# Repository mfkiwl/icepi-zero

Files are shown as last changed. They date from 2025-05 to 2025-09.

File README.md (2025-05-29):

# Icepi Zero - The portable FPGA development board. 



## What is the Icepi Zero?

Icepi Zero is an economical FPGA development board with a Raspberry Pi Zero form factor. It carries a Lattice ECP5 25F, enabling powerful designs while keeping a small portable size. It also has a HDMI port allowing easy digital video output.

[View PCB online](https://kicanvas.org/?github=https%3A%2F%2Fgithub.com%2Fcheyao%2Ficepi-zero%2Ftree%2Fmain%2Fhardware%2Fv1.1)



## Why Icepi Zero?

Currently most powerful FPGA boards on the market are expensive and bulky.

I've always wanted a low-cost portable FPGA with video output to make my own CPU, but there isn't any on the market.

The Icepi Zero aims to fix this. Carrying a powerful ECP5 FPGA on a small Raspberry Pi Zero form factor, it is the ultimate portable solution for FPGA development. Additionally packing a HDMI mini port and 3 USB-C ports, it allows interfacing with multiple external I/O devices.

Icepi Zero is for everyone: Students can use it to learn about the internals of modern processors. Gamers can use it to emulate old hardware. Programmers can use it to test their code on multiple architecturs.

Icepi Zero also has an on-board USB to JTAG converter, so no external programmers are needed. Moreover Icepi Zero is fully open-source, no strings attached. Fabricate your own boards if you want one!



## Features

- Raspberry Pi Zero form factor
- Lattice ECP5U FPGA:
    - 24k LUT
    - 112 KiB of RAM
- One MiniGPDI connector (it's HDM- but I don't have the money to buy a license...)
- Three USB-C Ports
- 256MiB 166MHz SDRAM
- MicroSD card slot
- On-board USB to JTAG and UART converter
- 40MHz external oscillator
- 128 Mbit of flash
- 4 user LEDs
- 1 user button

This powerful configuration allows the PCB to be used in numerous ways, including real time video processing, hardware AI acceleration and prototyping of ASICs.



## Usage

Check out the `firmware` folder for example code and compilation instructions!

## Contact

If there is any questions DM `@Cyao` on Hackclub Slack or `cyao.` on Discord. Mail is also accepted at `cyao _at_ duck.com`.

Thanks Hackclub for sponsering this! Check out [highway & undercity, a hackathon at Github HQ](https://highway.hackclub.com/?ref=recg6V5Pj0JbZghRM)

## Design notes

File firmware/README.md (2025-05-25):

# Icedev Zero Firmware

Welcome to the firmware folder! You can find numerous examples here:

- `blinky`: Classic LED counter!
- `counter`: Counter using the button as input :D
- `uart`: Uart transmission example

## Toolchain setup

Download the latest build of the [oss cad suit](https://github.com/YosysHQ/oss-cad-suite-build/releases/).

Unzip it anywhere and set shell command search path:
```
Linux              : export PATH=[path-to-bin]:$PATH
MacOS              : export PATH=[path-to-bin]:$PATH
Windows Powershell : $ENV:PATH = "[path-to-bin];" + $ENV:PATH
Windows cmd.exe    : PATH=[path-to-bin];%PATH%
```

## How to build

Just `cd` into the directories, and type `make`!

- `make install` installs the program to flash
- `make debug` installs the program to chip (bitstream lost on power loss)
- `make build` builds the bitstream
- `make clean` deletes all the temporary files
- `make` runs `make debug`

## Make your own!

Just copy the `icepi-zero.lpf` and `Makefile` to the root of your directory, call your main module `top`, and you are good to go!

## Pinout

To come soon

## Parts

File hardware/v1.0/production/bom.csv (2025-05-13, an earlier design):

Designator | Footprint | Quantity | Value | LCSC Part #
C1, C19, C23, C26, C42, C45, C47, C49, C7, C8, C9 | 0603 | 11 | 10uF | C19702
C10, C11, C12, C13, C14, C15, C18, C2, C20, C21, C24, C25, C27, C28, C38, C39, C40, C41, C43, C44, C46, C48, C50, C51, C52, C6 | 0402 | 26 | 100nF | C307331
C16, C17, C22, C3, C4, C5 | 0603 | 6 | 22uF | C59461
C29, C30, C31, C32, C33, C34, C35, C36 | 0402 | 8 | 22nF | C1532
C37 | 0402 | 1 | 100pF | C1546
D1, D2, D3, D4, D5 | 0603 | 5 | WHITE | C2290
D6 | 0603 | 1 | RED | C2286
FB1 | 0805 | 1 | 100R@100MHz | C1015
J2 | XKB Connection A71-05H4-111N1 | 1 | HDMI_C_1.3 | C2682170
J3, J4, J5 | USB_C_Receptacle_GCT_USB4105-xx-A_16P_TopMnt_Horizontal | 3 | USB_C_Receptacle_USB2.0_14P | C2765186
J6 | microSD_HC_SOFNG_TF-008 | 1 | Micro_SD_Card_Det2 | C428465
L1, L2, L3 | 0805 | 3 | 2.2uH | C1043
R1, R12, R14, R2, R3, R4, R5 | 0402 | 7 | 470 | C25117
R10, R36, R37, R38, R8 | 0402 | 5 | 15k | C25756
R11, R18, R19 | 0402 | 3 | 3.3k | C25890
R13, R32, R33, R34, R35, R6 | 0402 | 6 | 10k | C25744
R15 | 0402 | 1 | 100k | C25741
R16, R17, R22, R23, R24, R25, R31, R9 | 0402 | 8 | 4.7k | C25900
R20, R21, R26, R27, R29, R30 | 0402 | 6 | 5.1k | C25905
R28 | 0402 | 1 | 100 | C25076
R7 | 0402 | 1 | 12k | C25752
SW1 | SW_SPST_TL3342 | 1 | SW_Push | C318884
U1 | BGA-256_14.0x14.0mm_Layout16x16_P0.8mm_Ball0.45mm_Pad0.32mm_NSMD | 1 | ECP5U_12_CABGA256 | C1521614
U10 | TSOP-II-54_22.2x10.16mm_P0.8mm | 1 | W9825G6KH | C62246
U11 | SOIC-8_5.3x5.3mm_P1.27mm | 1 | W25Q128JVS | C97521
U2, U3, U4 | SOT-23-5 | 3 | TLV62569DBV | C141836
U5 | VSSOP-8_2.3x2mm_P0.5mm | 1 | PCA9306DC1 | C129510
U6 | QFN-20-1EP_4x4mm_P0.5mm_EP2.5x2.5mm | 1 | FT231XQ | C132159
U7, U8, U9 | Texas_DRT-3 | 3 | TPD2EUSB30A | C3011197
Y1 | Oscillator_SMD_SiT_PQFN-4Pin_2.5x2.0mm | 1 | SITxxxxxx-1x-33E-50.000000 | C1182928

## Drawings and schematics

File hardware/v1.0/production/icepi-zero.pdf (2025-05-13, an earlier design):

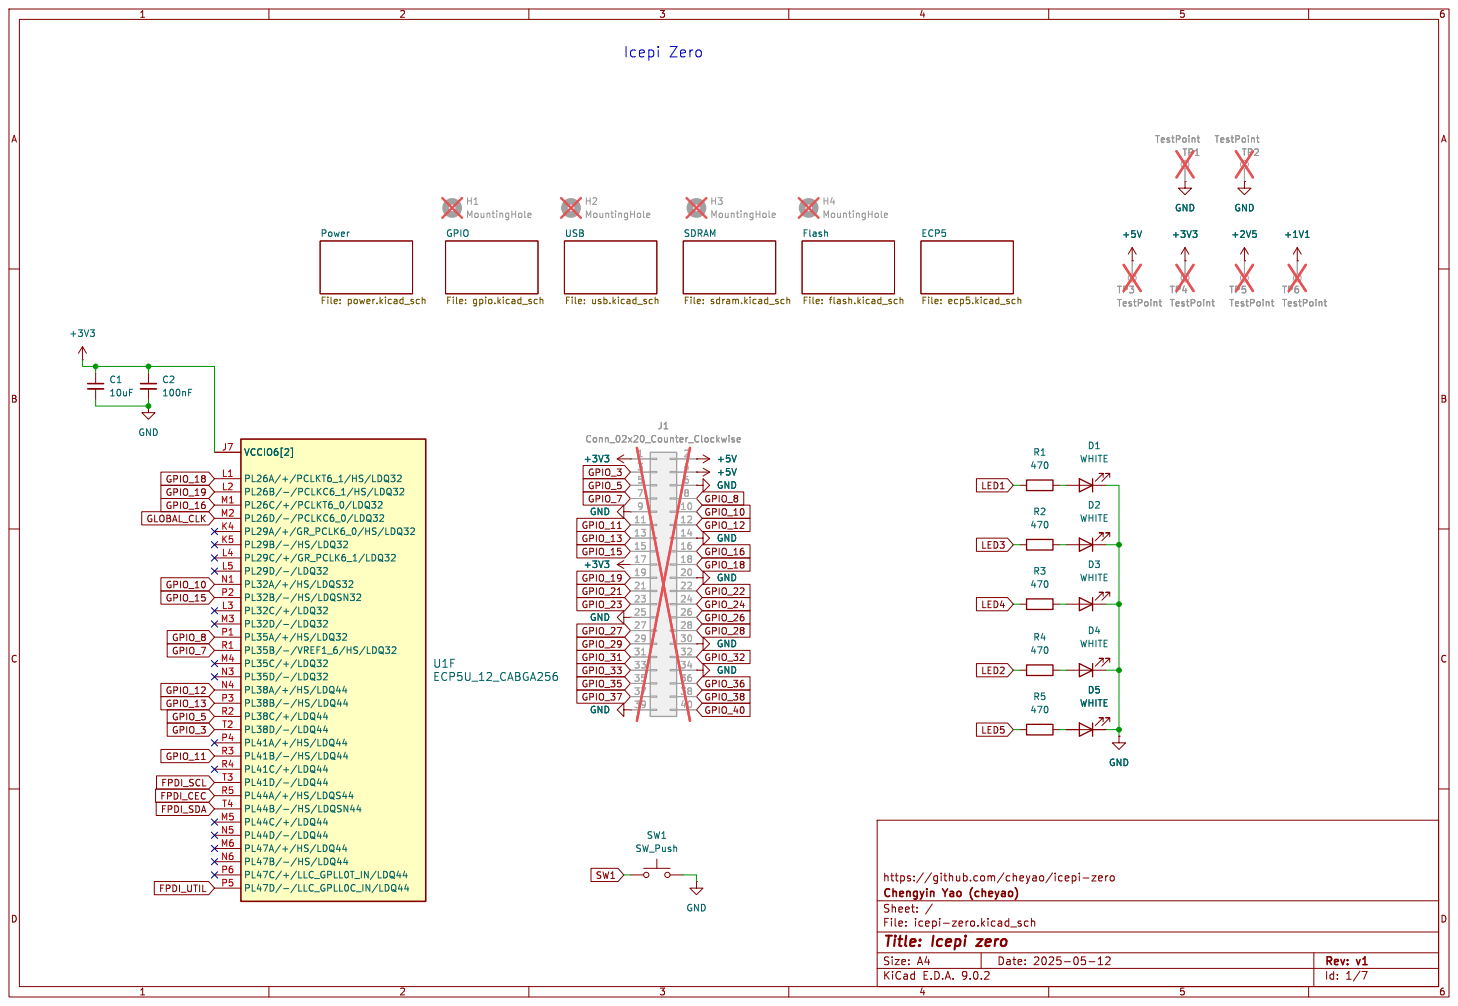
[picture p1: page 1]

TP1 TestPoint GND GND GND

https://github.com/cheyao/icepi-zero
File: icepi-zero.kicad_sch Sheet: / Chengyin Yao (cheyao)

Id: 1/7 Title: Icepi zero

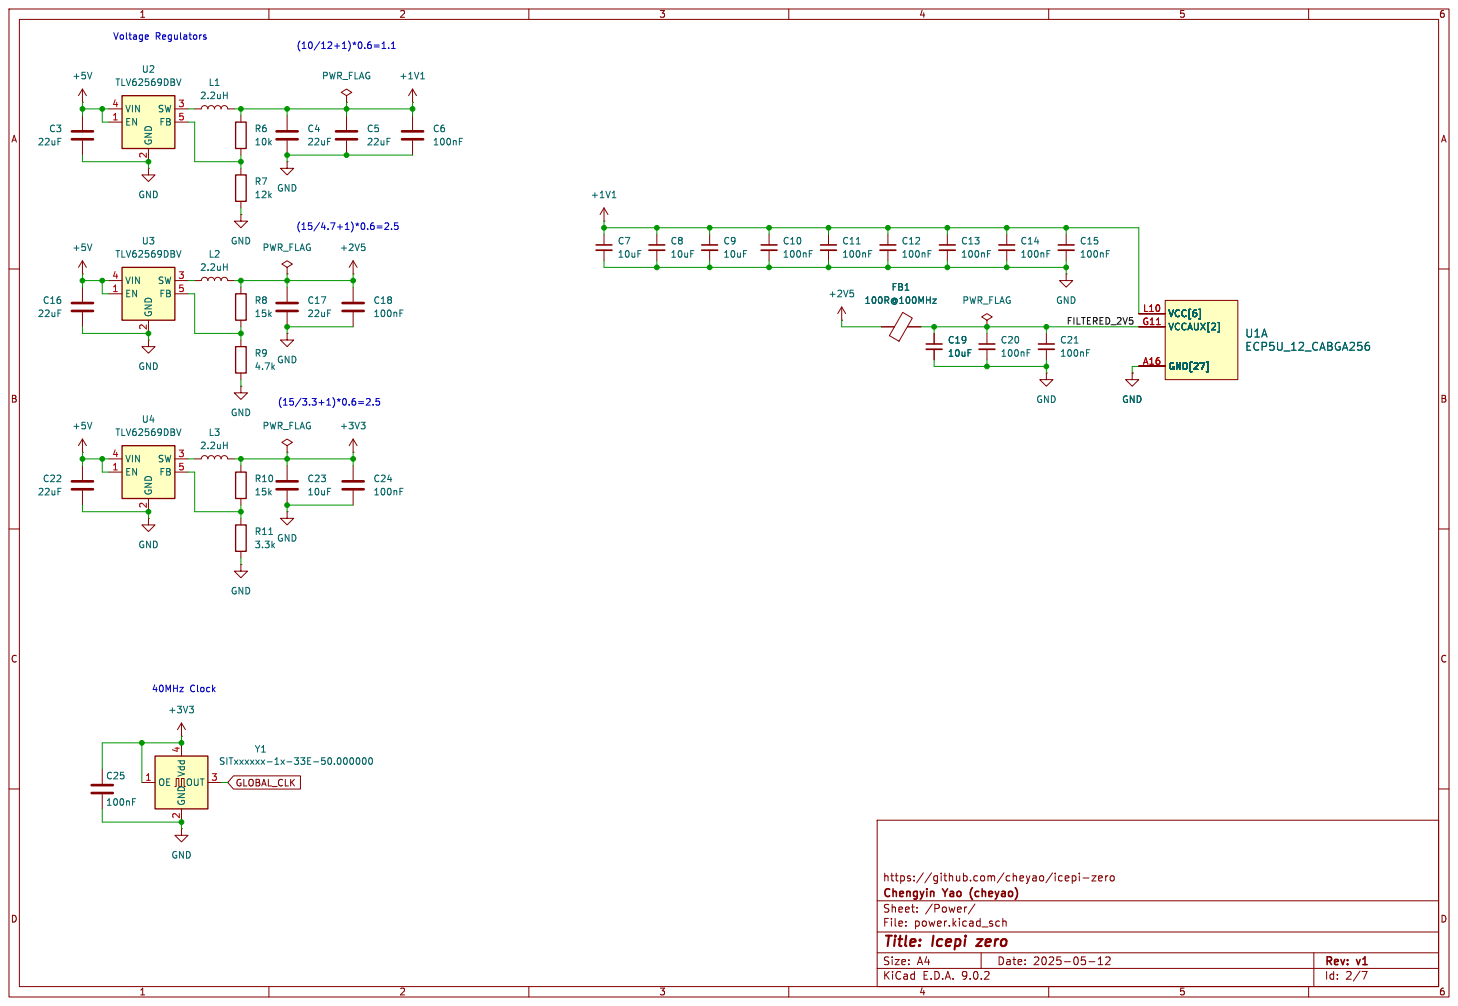
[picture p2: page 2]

https://github.com/cheyao/icepi-zero
File: power.kicad_sch Sheet: /Power/ Chengyin Yao (cheyao)

Id: 2/7 Title: Icepi zero

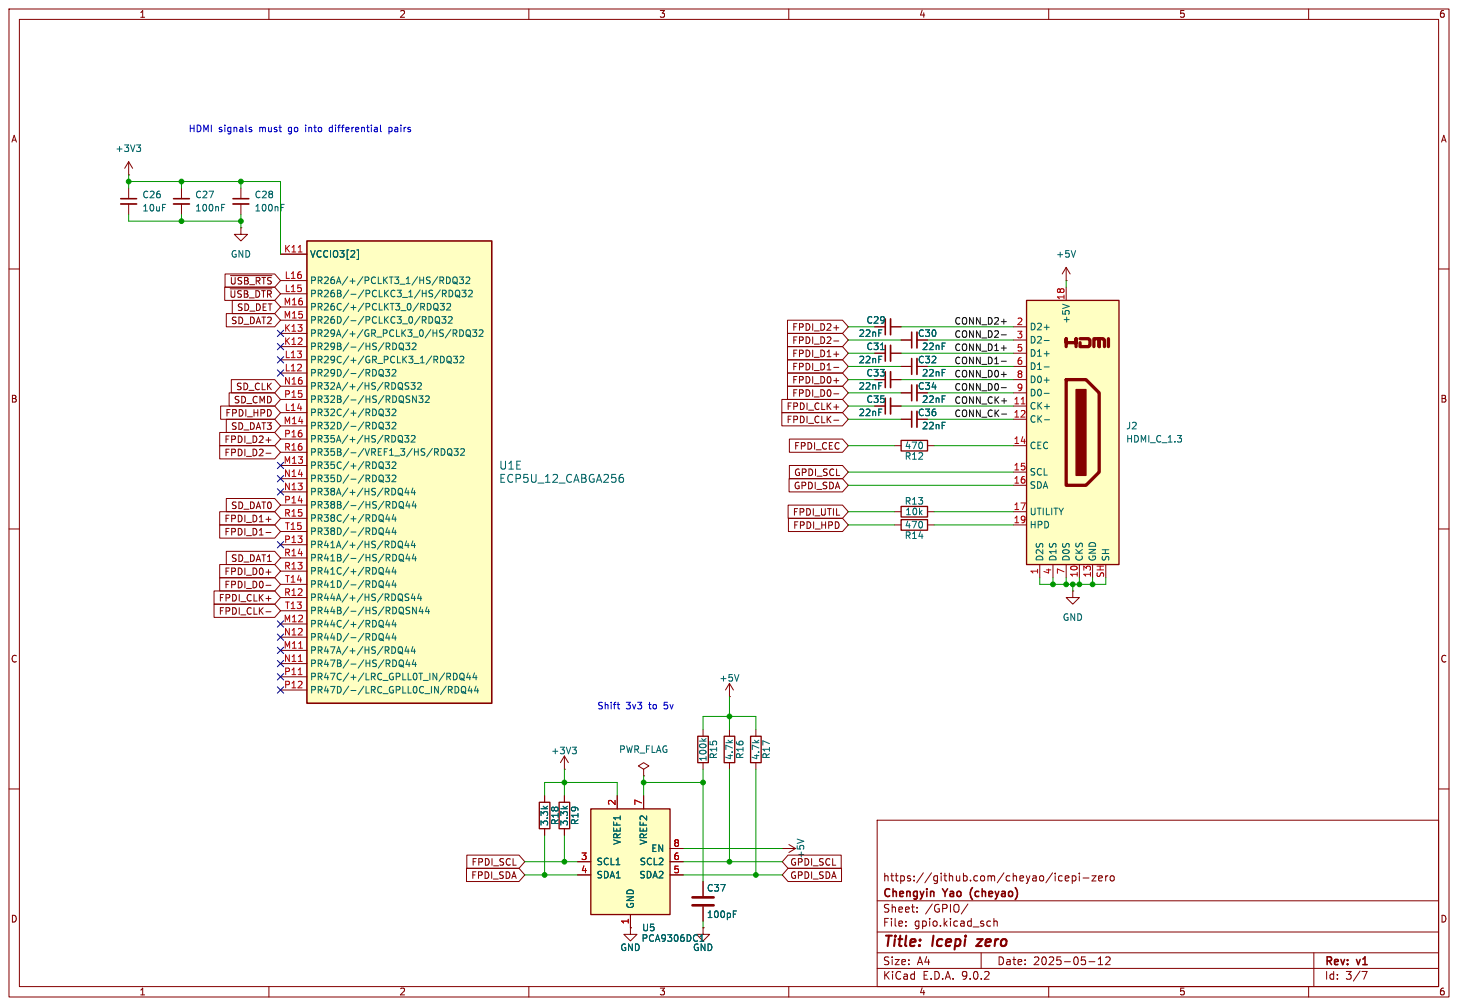
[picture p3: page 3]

7 CKS 10 GND 13 SH SH

https://github.com/cheyao/icepi-zero PWR_FLAG

File: gpio.kicad_sch Sheet: /GPIO/ Chengyin Yao (cheyao)

Id: 3/7 Title: Icepi zero

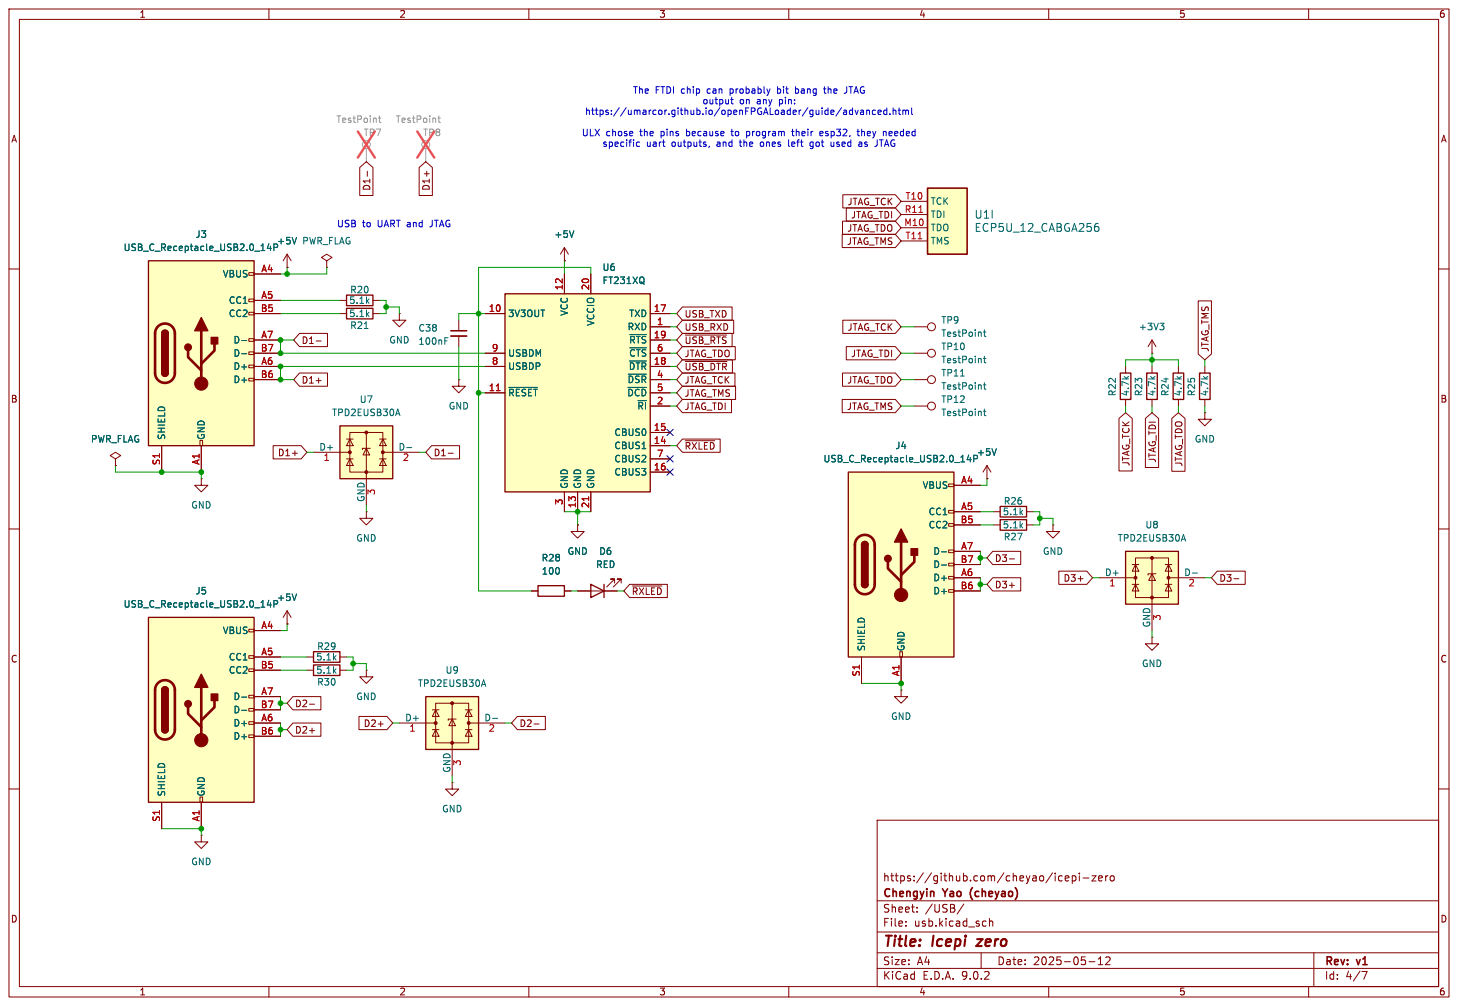
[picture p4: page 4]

https://umarcor.github.io/openFPGALoader/guide/advanced.html ULX chose the pins because to program their esp32, they needed
~{RXLED} JTAG_TCK

output on any pin:

USB to UART and JTAG

3 GND 13 VCCIO 20 GND 21 TXD 17 RXD 1 ~{RTS}19 ~{CTS}6 ~{DTR}18 ~{DSR}4 ~{DCD}5 ~{RI}2 CBUS0 15 CBUS1 14 CBUS2 7 CBUS3 16 U6 FT231XQ

3 GND 13 VCCIO 20 GND 21 TXD 17 RXD 1 ~{RTS}19 ~{CTS}6 ~{DTR}18 ~{DSR}4 ~{DCD}5 ~{RI}2 CBUS0 15 CBUS1 14 CBUS2 7 CBUS3 16 D6 RED

https://github.com/cheyao/icepi-zero
File: usb.kicad_sch Sheet: /USB/ Chengyin Yao (cheyao)

Id: 4/7 Title: Icepi zero

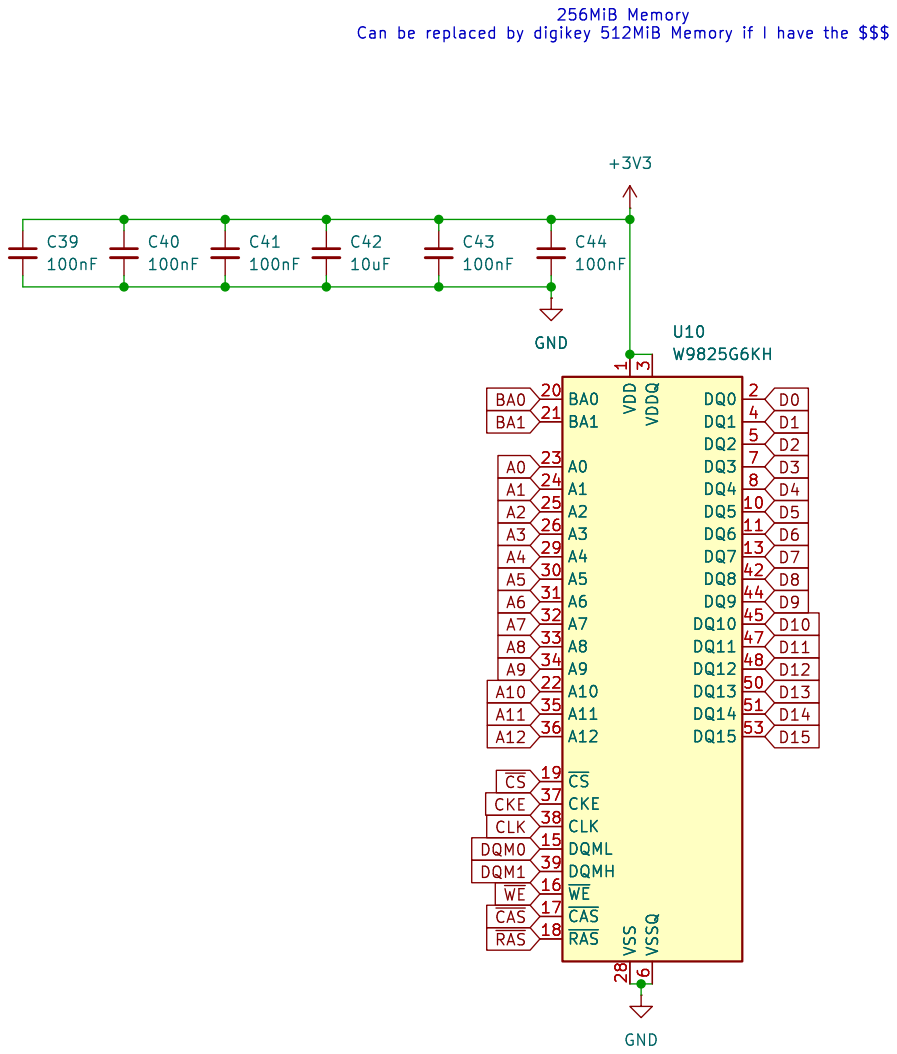
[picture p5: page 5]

https://github.com/cheyao/icepi-zero GND

File: sdram.kicad_sch Sheet: /SDRAM/ Chengyin Yao (cheyao)

Id: 5/7 Title: Icepi zero

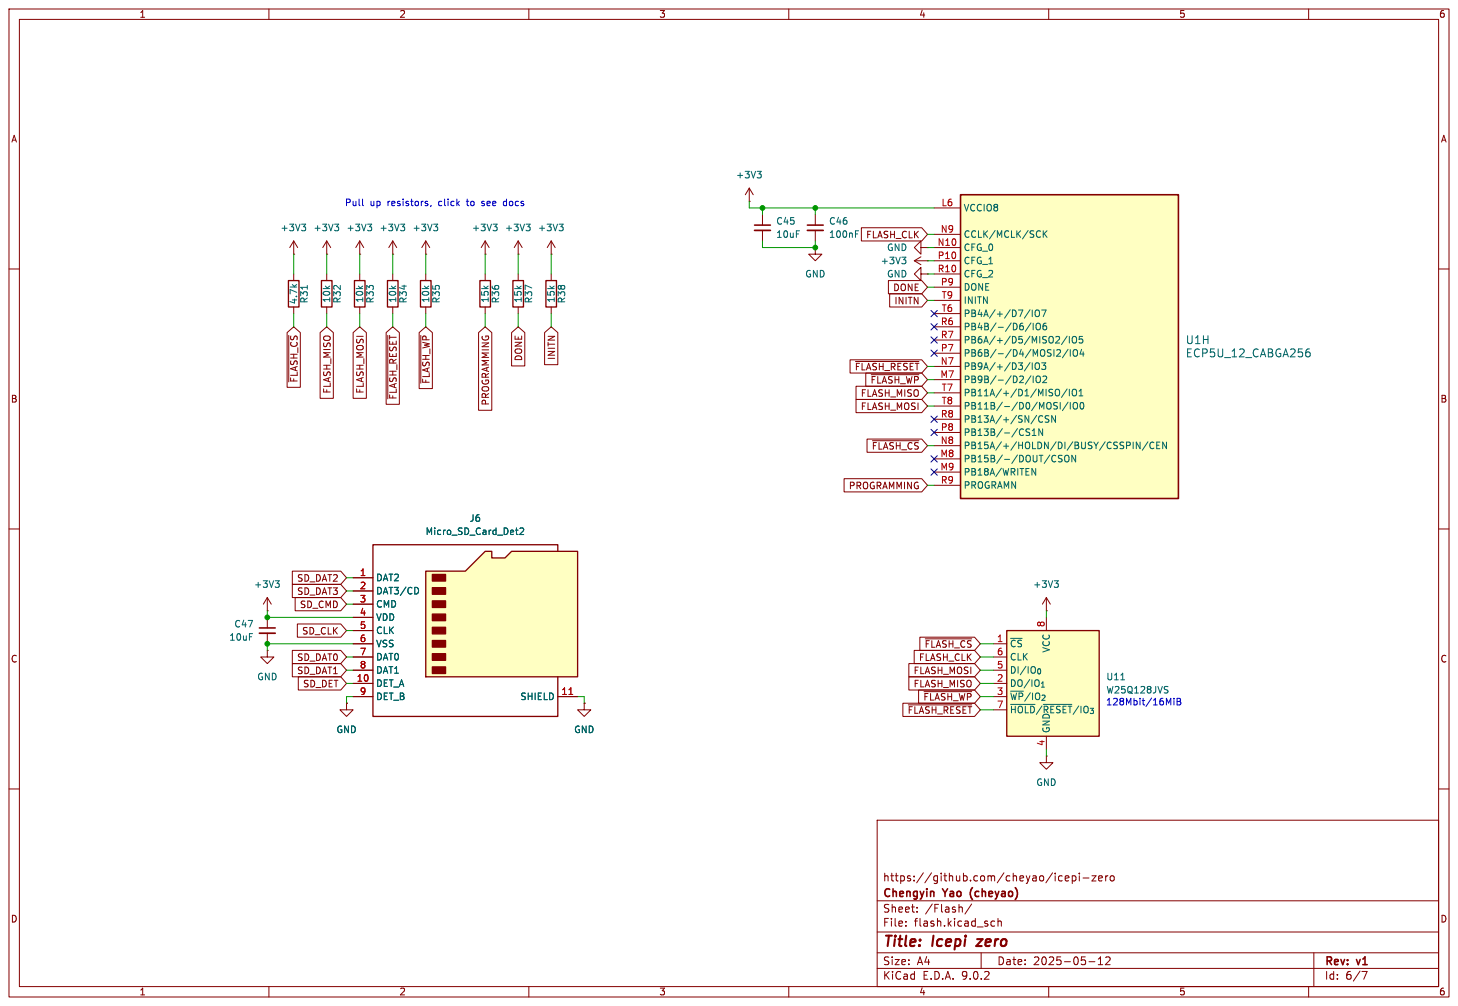
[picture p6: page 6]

File: flash.kicad_sch Sheet: /Flash/ Chengyin Yao (cheyao)

Id: 6/7 Title: Icepi zero

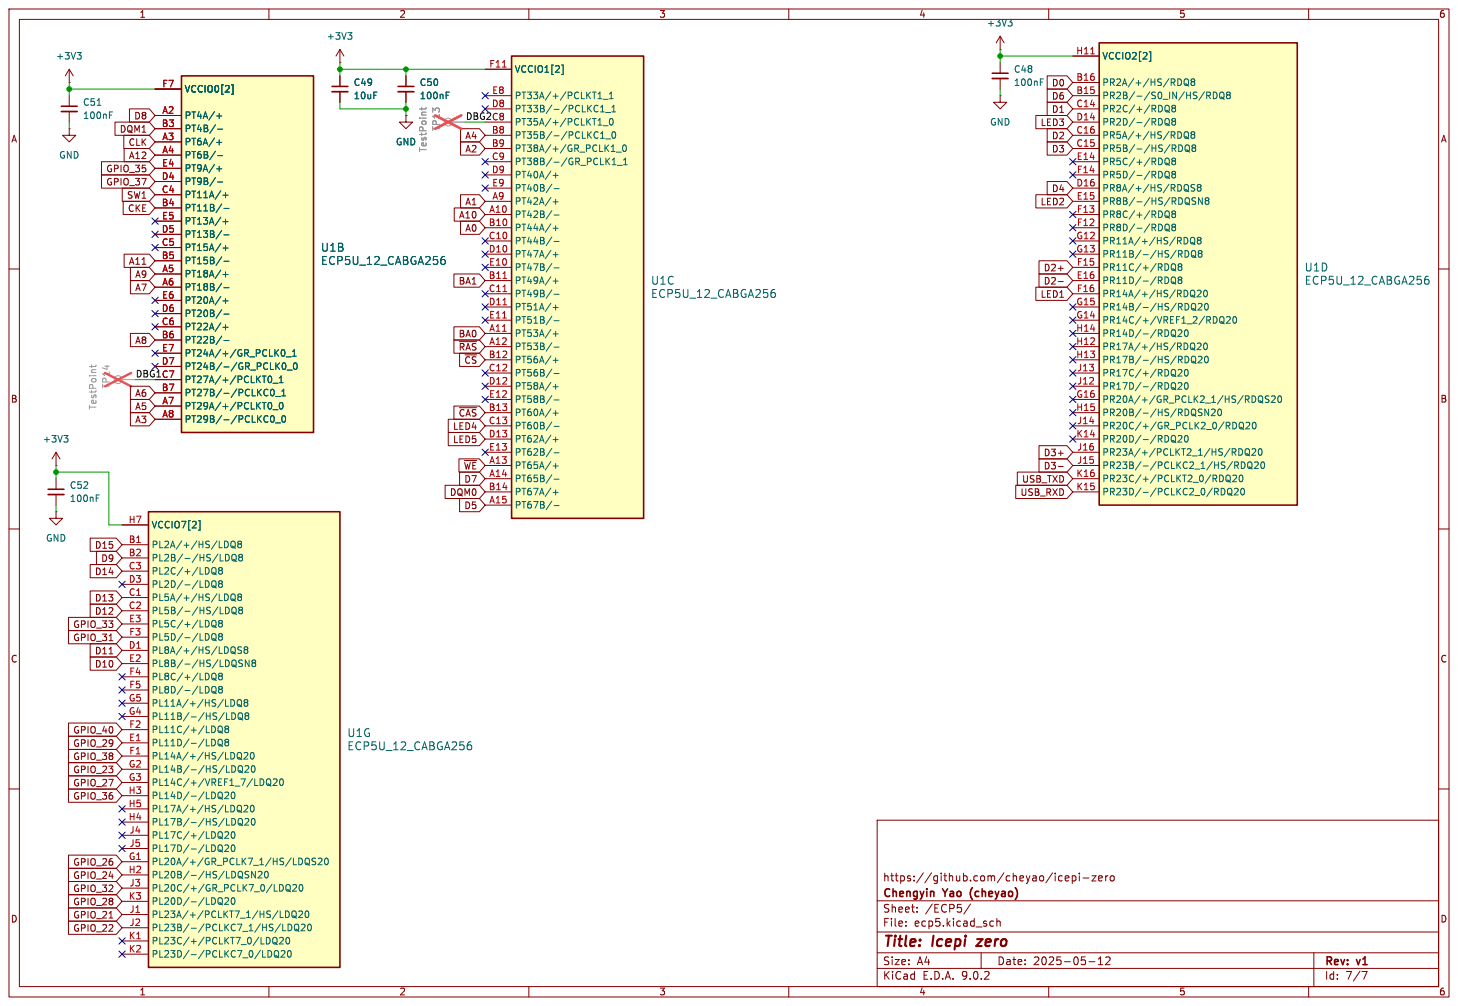
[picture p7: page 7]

https://github.com/cheyao/icepi-zero
File: ecp5.kicad_sch Sheet: /ECP5/ Chengyin Yao (cheyao)

Id: 7/7 Title: Icepi zero

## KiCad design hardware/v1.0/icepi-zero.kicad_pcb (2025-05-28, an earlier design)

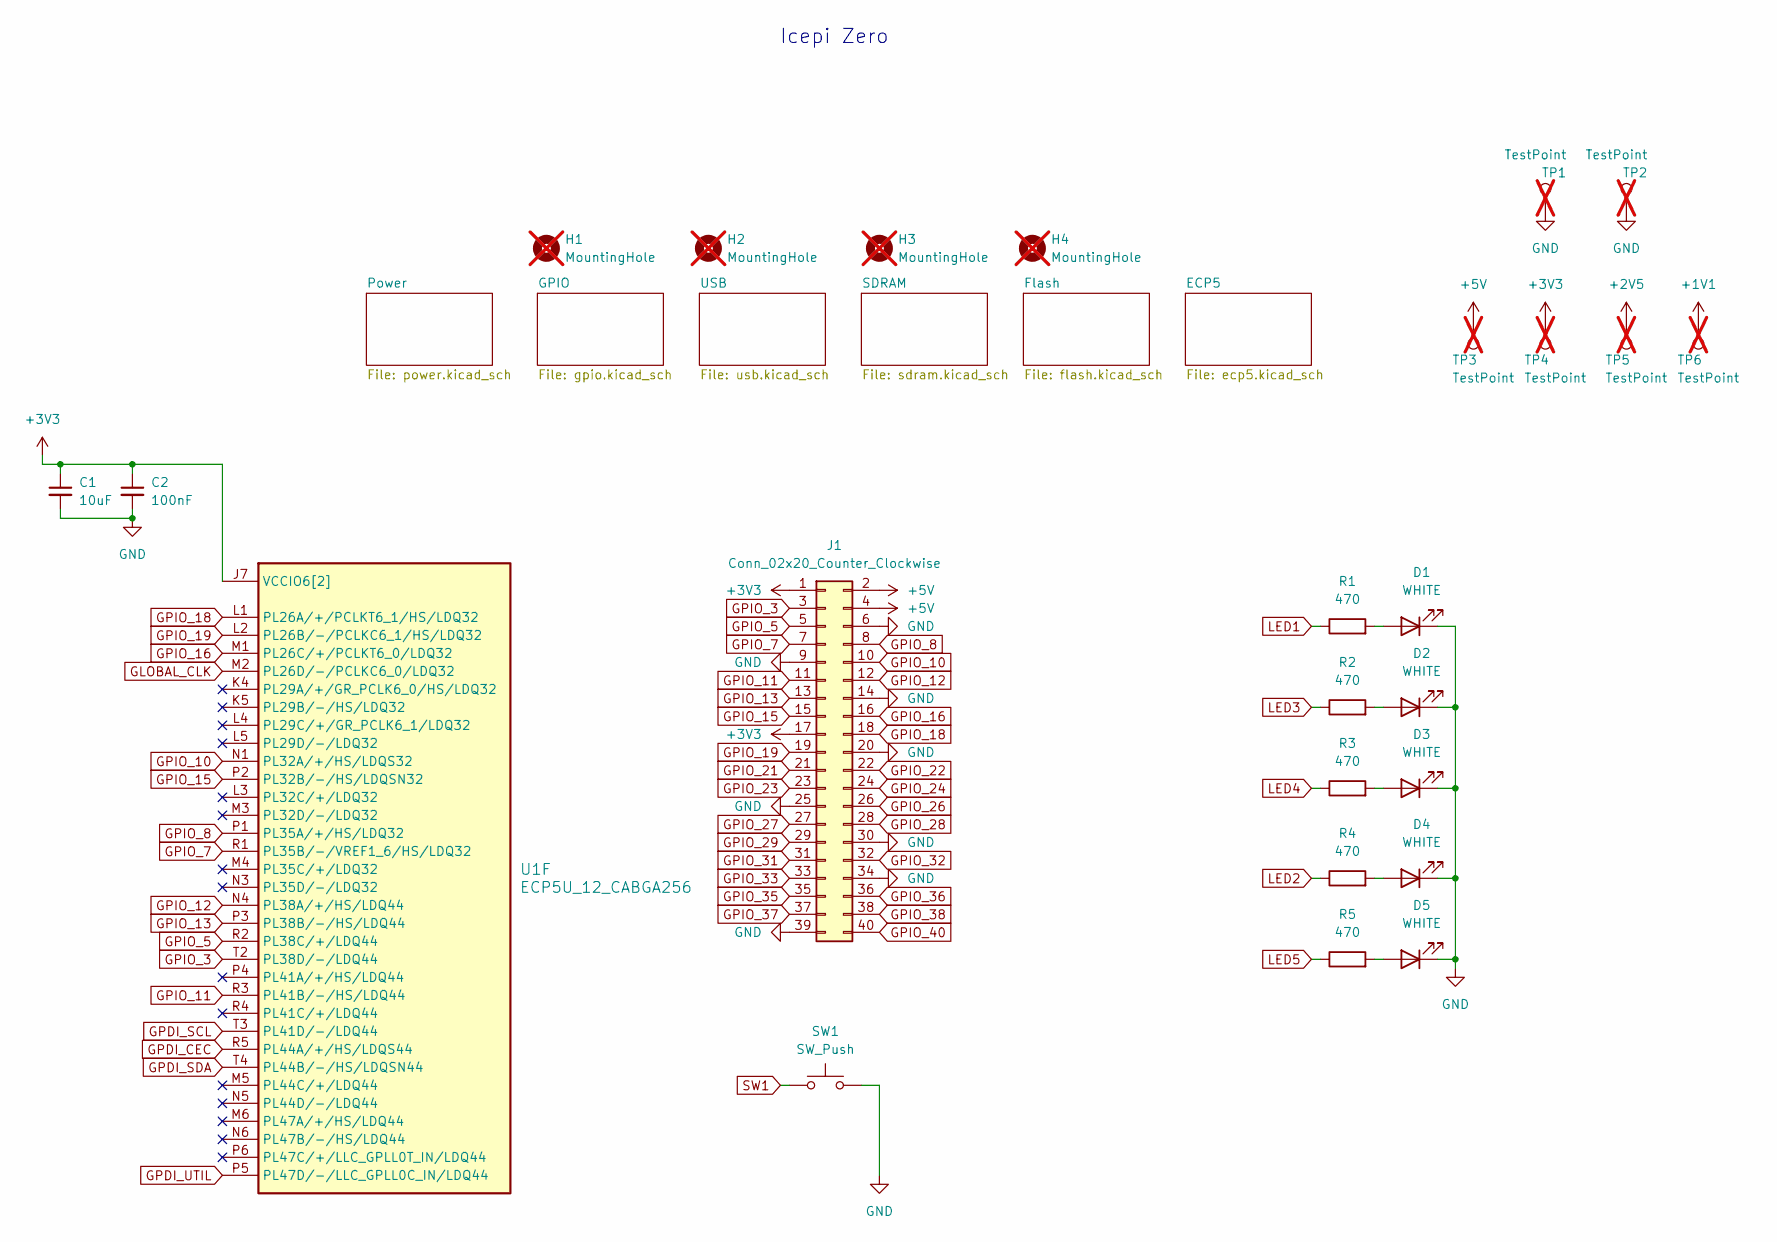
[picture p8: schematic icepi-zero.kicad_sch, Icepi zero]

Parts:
C1: 10uF; C_0603_1608Metric; LCSC Part # C19702
C2: 100nF; C_0402_1005Metric; LCSC Part # C307331
D1, D2, D3, D4, D5: WHITE; LED_0603_1608Metric; LCSC Part # C2290
H1, H2, H3, H4: MountingHole; MountingHole_2.7mm_M2.5; not fitted
J1: Conn_02x20_Counter_Clockwise; PinHeader_2x20_P2.54mm_Vertical
R1, R2, R3, R4, R5: 470; R_0402_1005Metric; LCSC Part # C25117
SW1: SW_Push; SW_SPST_B3U-1000P; LCSC Part # C2689695
TP1, TP2, TP3, TP4, TP5, TP6: TestPoint; TestPoint_Pad_D2.0mm; not fitted
U1: ECP5U_12_CABGA256; BGA-256_14.0x14.0mm_Layout16x16_P0.8mm_Ball0.45mm_Pad0.32mm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; LCSC Part # C1521614

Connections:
+1V1: TP6.1; also elsewhere on the board
+2V5: TP5.1; also elsewhere on the board
+3V3: C1.1, C2.1, J1.1, J1.17, TP4.1, U1.J6 (VCCIO6[2]), U1.J7 (VCCIO6[2]); also elsewhere on the board
+5V: J1.2, J1.4, TP3.1; also elsewhere on the board
GLOBAL_CLK: U1.M2 (PL26D/-/PCLKC6_0/LDQ32); also elsewhere on the board
GND: C1.2, C2.2, D1.1 (K), D2.1 (K), D3.1 (K), D4.1 (K), D5.1 (K), J1.6, J1.9, J1.14, J1.20, J1.25, J1.30, J1.34, J1.39, SW1.2, TP1.1, TP2.1; also elsewhere on the board
GPDI_CEC: U1.R5 (PL44A/+/HS/LDQS44); also elsewhere on the board
GPDI_SCL: U1.T3 (PL41D/-/LDQ44); also elsewhere on the board
GPDI_SDA: U1.T4 (PL44B/-/HS/LDQSN44); also elsewhere on the board
GPDI_UTIL: U1.P5 (PL47D/-/LLC_GPLL0C_IN/LDQ44); also elsewhere on the board
GPIO_3: J1.3, U1.T2 (PL38D/-/LDQ44)
GPIO_5: J1.5, U1.R2 (PL38C/+/LDQ44)
GPIO_7: J1.7, U1.R1 (PL35B/-/VREF1_6/HS/LDQ32)
GPIO_8: J1.8, U1.P1 (PL35A/+/HS/LDQ32)
GPIO_10: J1.10, U1.N1 (PL32A/+/HS/LDQS32)
GPIO_11: J1.11, U1.R3 (PL41B/-/HS/LDQ44)
GPIO_12: J1.12, U1.N4 (PL38A/+/HS/LDQ44)
GPIO_13: J1.13, U1.P3 (PL38B/-/HS/LDQ44)
GPIO_15: J1.15, U1.P2 (PL32B/-/HS/LDQSN32)
GPIO_16: J1.16, U1.M1 (PL26C/+/PCLKT6_0/LDQ32)
GPIO_18: J1.18, U1.L1 (PL26A/+/PCLKT6_1/HS/LDQ32)
GPIO_19: J1.19, U1.L2 (PL26B/-/PCLKC6_1/HS/LDQ32)
GPIO_21: J1.21; also elsewhere on the board
GPIO_22: J1.22; also elsewhere on the board
GPIO_23: J1.23; also elsewhere on the board
GPIO_24: J1.24; also elsewhere on the board
GPIO_26: J1.26; also elsewhere on the board
GPIO_27: J1.27; also elsewhere on the board
GPIO_28: J1.28; also elsewhere on the board
GPIO_29: J1.29; also elsewhere on the board
GPIO_31: J1.31; also elsewhere on the board
GPIO_32: J1.32; also elsewhere on the board
GPIO_33: J1.33; also elsewhere on the board
GPIO_35: J1.35; also elsewhere on the board
GPIO_36: J1.36; also elsewhere on the board
GPIO_37: J1.37; also elsewhere on the board
GPIO_38: J1.38; also elsewhere on the board
GPIO_40: J1.40; also elsewhere on the board
LED1: R1.1; also elsewhere on the board
LED2: R4.1; also elsewhere on the board
LED3: R2.1; also elsewhere on the board
LED4: R3.1; also elsewhere on the board
LED5: R5.1; also elsewhere on the board
unnamed: D1.2 (A), R1.2
unnamed: D2.2 (A), R2.2
unnamed: D3.2 (A), R3.2
unnamed: D4.2 (A), R4.2
unnamed: D5.2 (A), R5.2
SW1: SW1.1; also elsewhere on the board

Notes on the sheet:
Icepi Zero

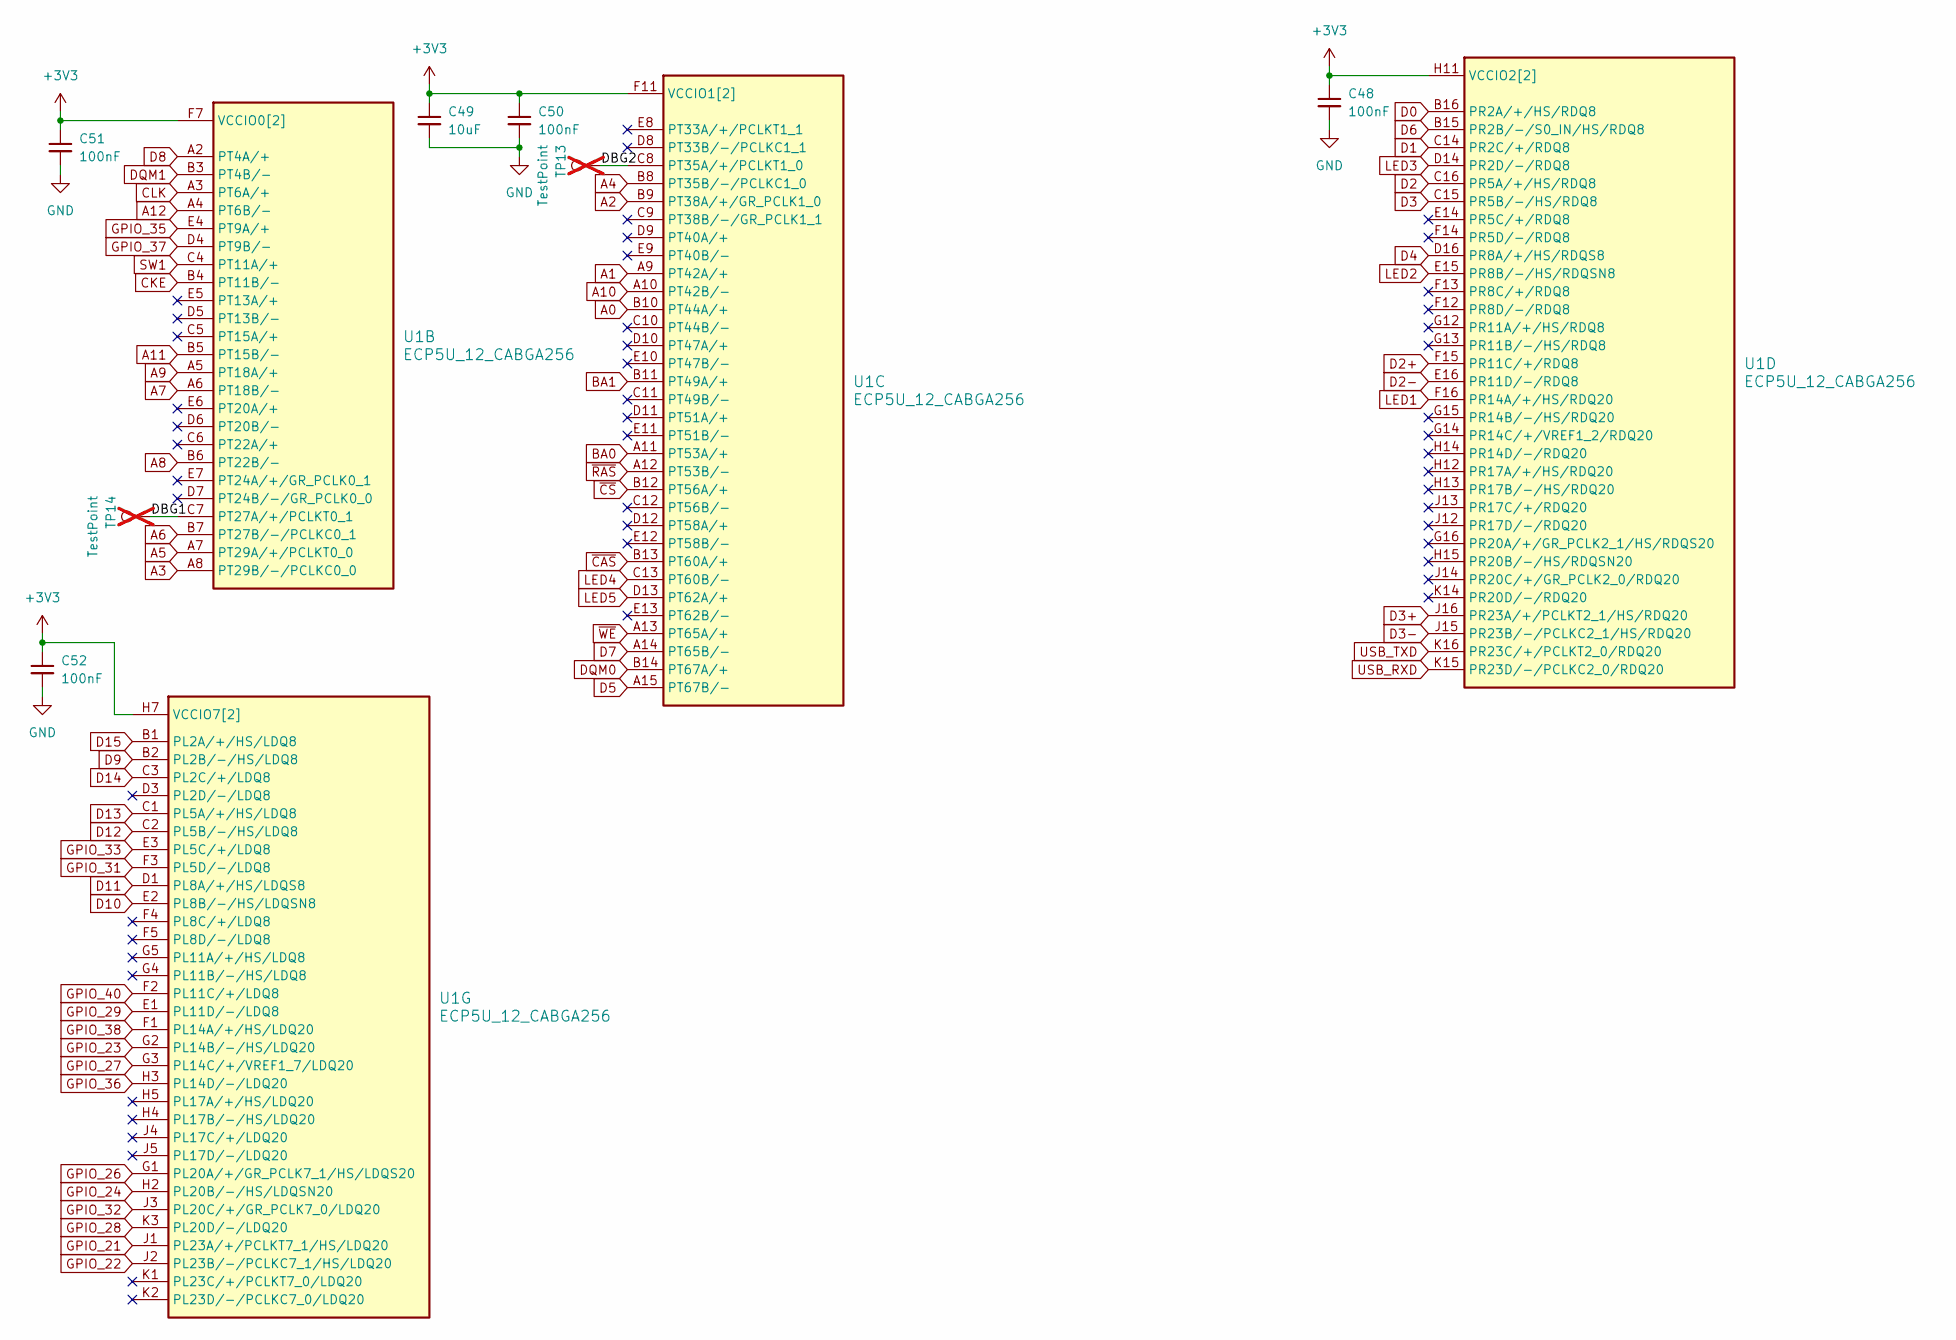
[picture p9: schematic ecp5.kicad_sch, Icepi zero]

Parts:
C48, C50, C51, C52: 100nF; C_0402_1005Metric; LCSC Part # C307331
C49: 10uF; C_0603_1608Metric; LCSC Part # C19702
TP13, TP14: TestPoint; TestPoint_Pad_D1.0mm; not fitted
U1: ECP5U_12_CABGA256; BGA-256_14.0x14.0mm_Layout16x16_P0.8mm_Ball0.45mm_Pad0.32mm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; LCSC Part # C1521614

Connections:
+3V3: C48.1, C49.1, C50.1, C51.1, C52.1, U1.F6 (VCCIO0[2]), U1.F7 (VCCIO0[2]), U1.F10 (VCCIO1[2]), U1.F11 (VCCIO1[2]), U1.H6 (VCCIO7[2]), U1.H7 (VCCIO7[2]), U1.H11 (VCCIO2[2]), U1.J11 (VCCIO2[2]); also elsewhere on the board
/ECP5/DBG1: TP14.1, U1.C7 (PT27A/+/PCLKT0_1)
/ECP5/DBG2: TP13.1, U1.C8 (PT35A/+/PCLKT1_0)
A0: U1.B10 (PT44A/+); also elsewhere on the board
A1: U1.A9 (PT42A/+); also elsewhere on the board
A2: U1.B9 (PT38A/+/GR_PCLK1_0); also elsewhere on the board
A3: U1.A8 (PT29B/-/PCLKC0_0); also elsewhere on the board
A4: U1.B8 (PT35B/-/PCLKC1_0); also elsewhere on the board
A5: U1.A7 (PT29A/+/PCLKT0_0); also elsewhere on the board
A6: U1.B7 (PT27B/-/PCLKC0_1); also elsewhere on the board
A7: U1.A6 (PT18B/-); also elsewhere on the board
A8: U1.B6 (PT22B/-); also elsewhere on the board
A9: U1.A5 (PT18A/+); also elsewhere on the board
A10: U1.A10 (PT42B/-); also elsewhere on the board
A11: U1.B5 (PT15B/-); also elsewhere on the board
A12: U1.A4 (PT6B/-); also elsewhere on the board
BA0: U1.A11 (PT53A/+); also elsewhere on the board
BA1: U1.B11 (PT49A/+); also elsewhere on the board
CKE: U1.B4 (PT11B/-); also elsewhere on the board
CLK: U1.A3 (PT6A/+); also elsewhere on the board
D0: U1.B16 (PR2A/+/HS/RDQ8); also elsewhere on the board
D1: U1.C14 (PR2C/+/RDQ8); also elsewhere on the board
D2: U1.C16 (PR5A/+/HS/RDQ8); also elsewhere on the board
D2+: U1.F15 (PR11C/+/RDQ8); also elsewhere on the board
D2-: U1.E16 (PR11D/-/RDQ8); also elsewhere on the board
D3: U1.C15 (PR5B/-/HS/RDQ8); also elsewhere on the board
D3+: U1.J16 (PR23A/+/PCLKT2_1/HS/RDQ20); also elsewhere on the board
D3-: U1.J15 (PR23B/-/PCLKC2_1/HS/RDQ20); also elsewhere on the board
D4: U1.D16 (PR8A/+/HS/RDQS8); also elsewhere on the board
D5: U1.A15 (PT67B/-); also elsewhere on the board
D6: U1.B15 (PR2B/-/S0_IN/HS/RDQ8); also elsewhere on the board
D7: U1.A14 (PT65B/-); also elsewhere on the board
D8: U1.A2 (PT4A/+); also elsewhere on the board
D9: U1.B2 (PL2B/-/HS/LDQ8); also elsewhere on the board
D10: U1.E2 (PL8B/-/HS/LDQSN8); also elsewhere on the board
D11: U1.D1 (PL8A/+/HS/LDQS8); also elsewhere on the board
D12: U1.C2 (PL5B/-/HS/LDQ8); also elsewhere on the board
D13: U1.C1 (PL5A/+/HS/LDQ8); also elsewhere on the board
D14: U1.C3 (PL2C/+/LDQ8); also elsewhere on the board
D15: U1.B1 (PL2A/+/HS/LDQ8); also elsewhere on the board
DQM0: U1.B14 (PT67A/+); also elsewhere on the board
DQM1: U1.B3 (PT4B/-); also elsewhere on the board
GND: C48.2, C49.2, C50.2, C51.2, C52.2; also elsewhere on the board
GPIO_21: U1.J1 (PL23A/+/PCLKT7_1/HS/LDQ20); also elsewhere on the board
GPIO_22: U1.J2 (PL23B/-/PCLKC7_1/HS/LDQ20); also elsewhere on the board
GPIO_23: U1.G2 (PL14B/-/HS/LDQ20); also elsewhere on the board
GPIO_24: U1.H2 (PL20B/-/HS/LDQSN20); also elsewhere on the board
GPIO_26: U1.G1 (PL20A/+/GR_PCLK7_1/HS/LDQS20); also elsewhere on the board
GPIO_27: U1.G3 (PL14C/+/VREF1_7/LDQ20); also elsewhere on the board
GPIO_28: U1.K3 (PL20D/-/LDQ20); also elsewhere on the board
GPIO_29: U1.E1 (PL11D/-/LDQ8); also elsewhere on the board
GPIO_31: U1.F3 (PL5D/-/LDQ8); also elsewhere on the board
GPIO_32: U1.J3 (PL20C/+/GR_PCLK7_0/LDQ20); also elsewhere on the board
GPIO_33: U1.E3 (PL5C/+/LDQ8); also elsewhere on the board
GPIO_35: U1.E4 (PT9A/+); also elsewhere on the board
GPIO_36: U1.H3 (PL14D/-/LDQ20); also elsewhere on the board
GPIO_37: U1.D4 (PT9B/-); also elsewhere on the board
GPIO_38: U1.F1 (PL14A/+/HS/LDQ20); also elsewhere on the board
GPIO_40: U1.F2 (PL11C/+/LDQ8); also elsewhere on the board
LED1: U1.F16 (PR14A/+/HS/RDQ20); also elsewhere on the board
LED2: U1.E15 (PR8B/-/HS/RDQSN8); also elsewhere on the board
LED3: U1.D14 (PR2D/-/RDQ8); also elsewhere on the board
LED4: U1.C13 (PT60B/-); also elsewhere on the board
LED5: U1.D13 (PT62A/+); also elsewhere on the board
SW1: U1.C4 (PT11A/+); also elsewhere on the board
USB_RXD: U1.K15 (PR23D/-/PCLKC2_0/RDQ20); also elsewhere on the board
USB_TXD: U1.K16 (PR23C/+/PCLKT2_0/RDQ20); also elsewhere on the board
~CAS: U1.B13 (PT60A/+); also elsewhere on the board
~CS: U1.B12 (PT56A/+); also elsewhere on the board
~RAS: U1.A12 (PT53B/-); also elsewhere on the board
~WE: U1.A13 (PT65A/+); also elsewhere on the board

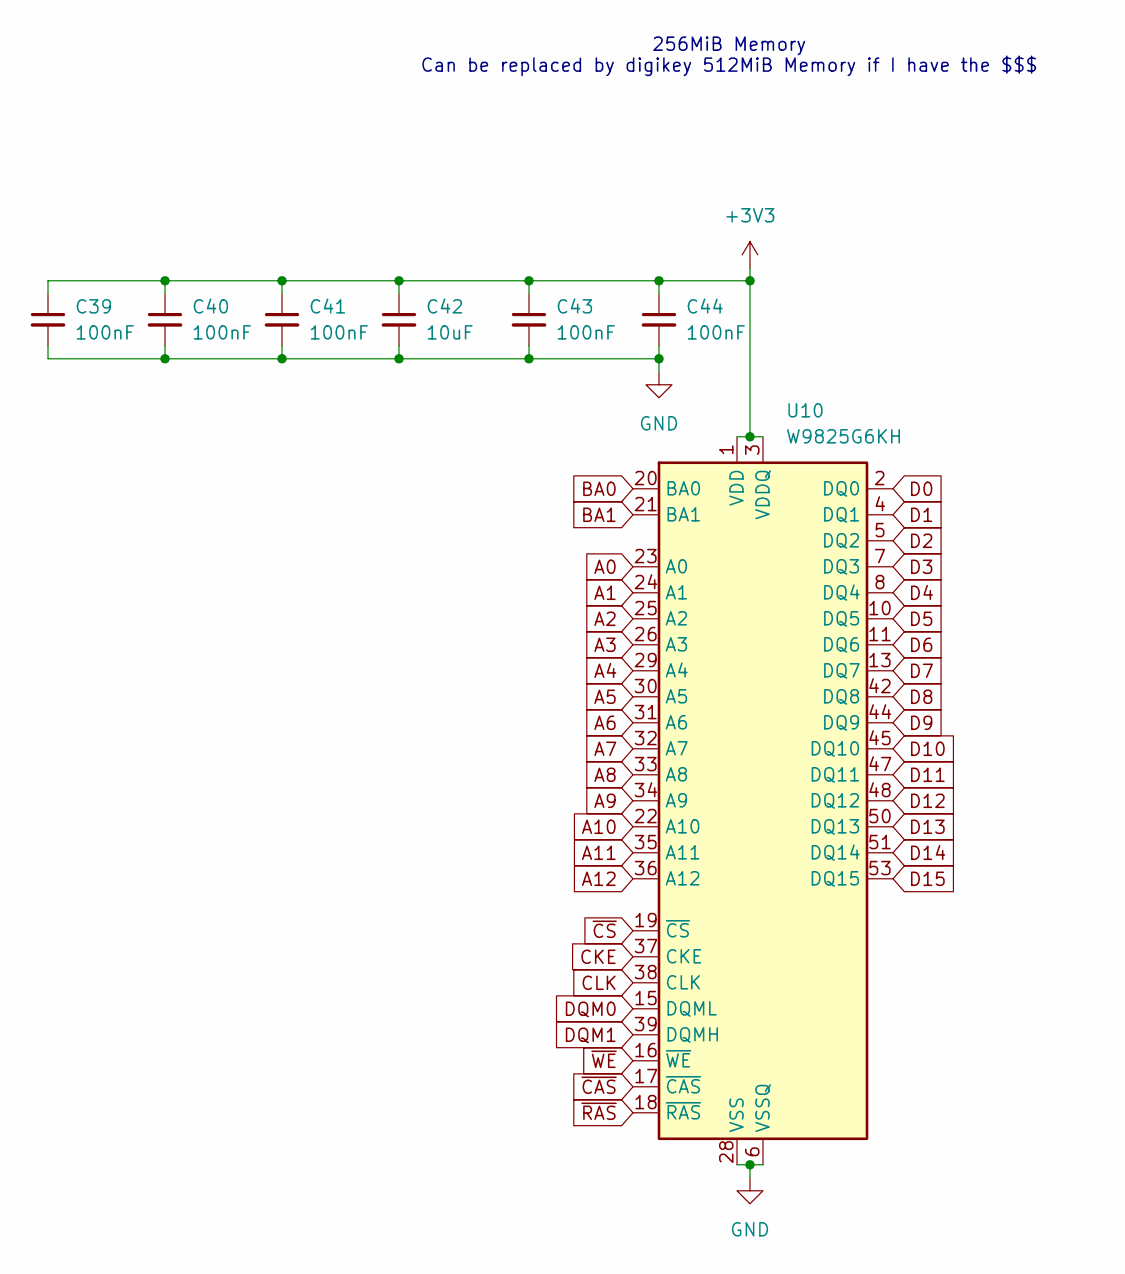
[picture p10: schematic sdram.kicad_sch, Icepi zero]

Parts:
C39, C40, C41, C43, C44: 100nF; C_0402_1005Metric; LCSC Part # C307331
C42: 10uF; C_0603_1608Metric; LCSC Part # C19702
U10: W9825G6KH; TSOP-II-54_22.2x10.16mm_P0.8mm; LCSC Part # C62246

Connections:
+3V3: C39.1, C40.1, C41.1, C42.1, C43.1, C44.1, U10.1 (VDD), U10.3 (VDDQ), U10.9 (VDDQ), U10.14 (VDD), U10.27 (VDD), U10.43 (VDDQ), U10.49 (VDDQ); also elsewhere on the board
A0: U10.23 (A0); also elsewhere on the board
A1: U10.24 (A1); also elsewhere on the board
A2: U10.25 (A2); also elsewhere on the board
A3: U10.26 (A3); also elsewhere on the board
A4: U10.29 (A4); also elsewhere on the board
A5: U10.30 (A5); also elsewhere on the board
A6: U10.31 (A6); also elsewhere on the board
A7: U10.32 (A7); also elsewhere on the board
A8: U10.33 (A8); also elsewhere on the board
A9: U10.34 (A9); also elsewhere on the board
A10: U10.22 (A10); also elsewhere on the board
A11: U10.35 (A11); also elsewhere on the board
A12: U10.36 (A12); also elsewhere on the board
BA0: U10.20 (BA0); also elsewhere on the board
BA1: U10.21 (BA1); also elsewhere on the board
CKE: U10.37 (CKE); also elsewhere on the board
CLK: U10.38 (CLK); also elsewhere on the board
D0: U10.2 (DQ0); also elsewhere on the board
D1: U10.4 (DQ1); also elsewhere on the board
D2: U10.5 (DQ2); also elsewhere on the board
D3: U10.7 (DQ3); also elsewhere on the board
D4: U10.8 (DQ4); also elsewhere on the board
D5: U10.10 (DQ5); also elsewhere on the board
D6: U10.11 (DQ6); also elsewhere on the board
D7: U10.13 (DQ7); also elsewhere on the board
D8: U10.42 (DQ8); also elsewhere on the board
D9: U10.44 (DQ9); also elsewhere on the board
D10: U10.45 (DQ10); also elsewhere on the board
D11: U10.47 (DQ11); also elsewhere on the board
D12: U10.48 (DQ12); also elsewhere on the board
D13: U10.50 (DQ13); also elsewhere on the board
D14: U10.51 (DQ14); also elsewhere on the board
D15: U10.53 (DQ15); also elsewhere on the board
DQM0: U10.15 (DQML); also elsewhere on the board
DQM1: U10.39 (DQMH); also elsewhere on the board
GND: C39.2, C40.2, C41.2, C42.2, C43.2, C44.2, U10.6 (VSSQ), U10.12 (VSSQ), U10.28 (VSS), U10.41 (VSS), U10.46 (VSSQ), U10.52 (VSSQ), U10.54 (VSS); also elsewhere on the board
~CAS: U10.17 (~CAS); also elsewhere on the board
~CS: U10.19 (~CS); also elsewhere on the board
~RAS: U10.18 (~RAS); also elsewhere on the board
~WE: U10.16 (~WE); also elsewhere on the board

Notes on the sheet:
256MiB Memory Can be replaced by digikey 512MiB Memory if I have the $$$

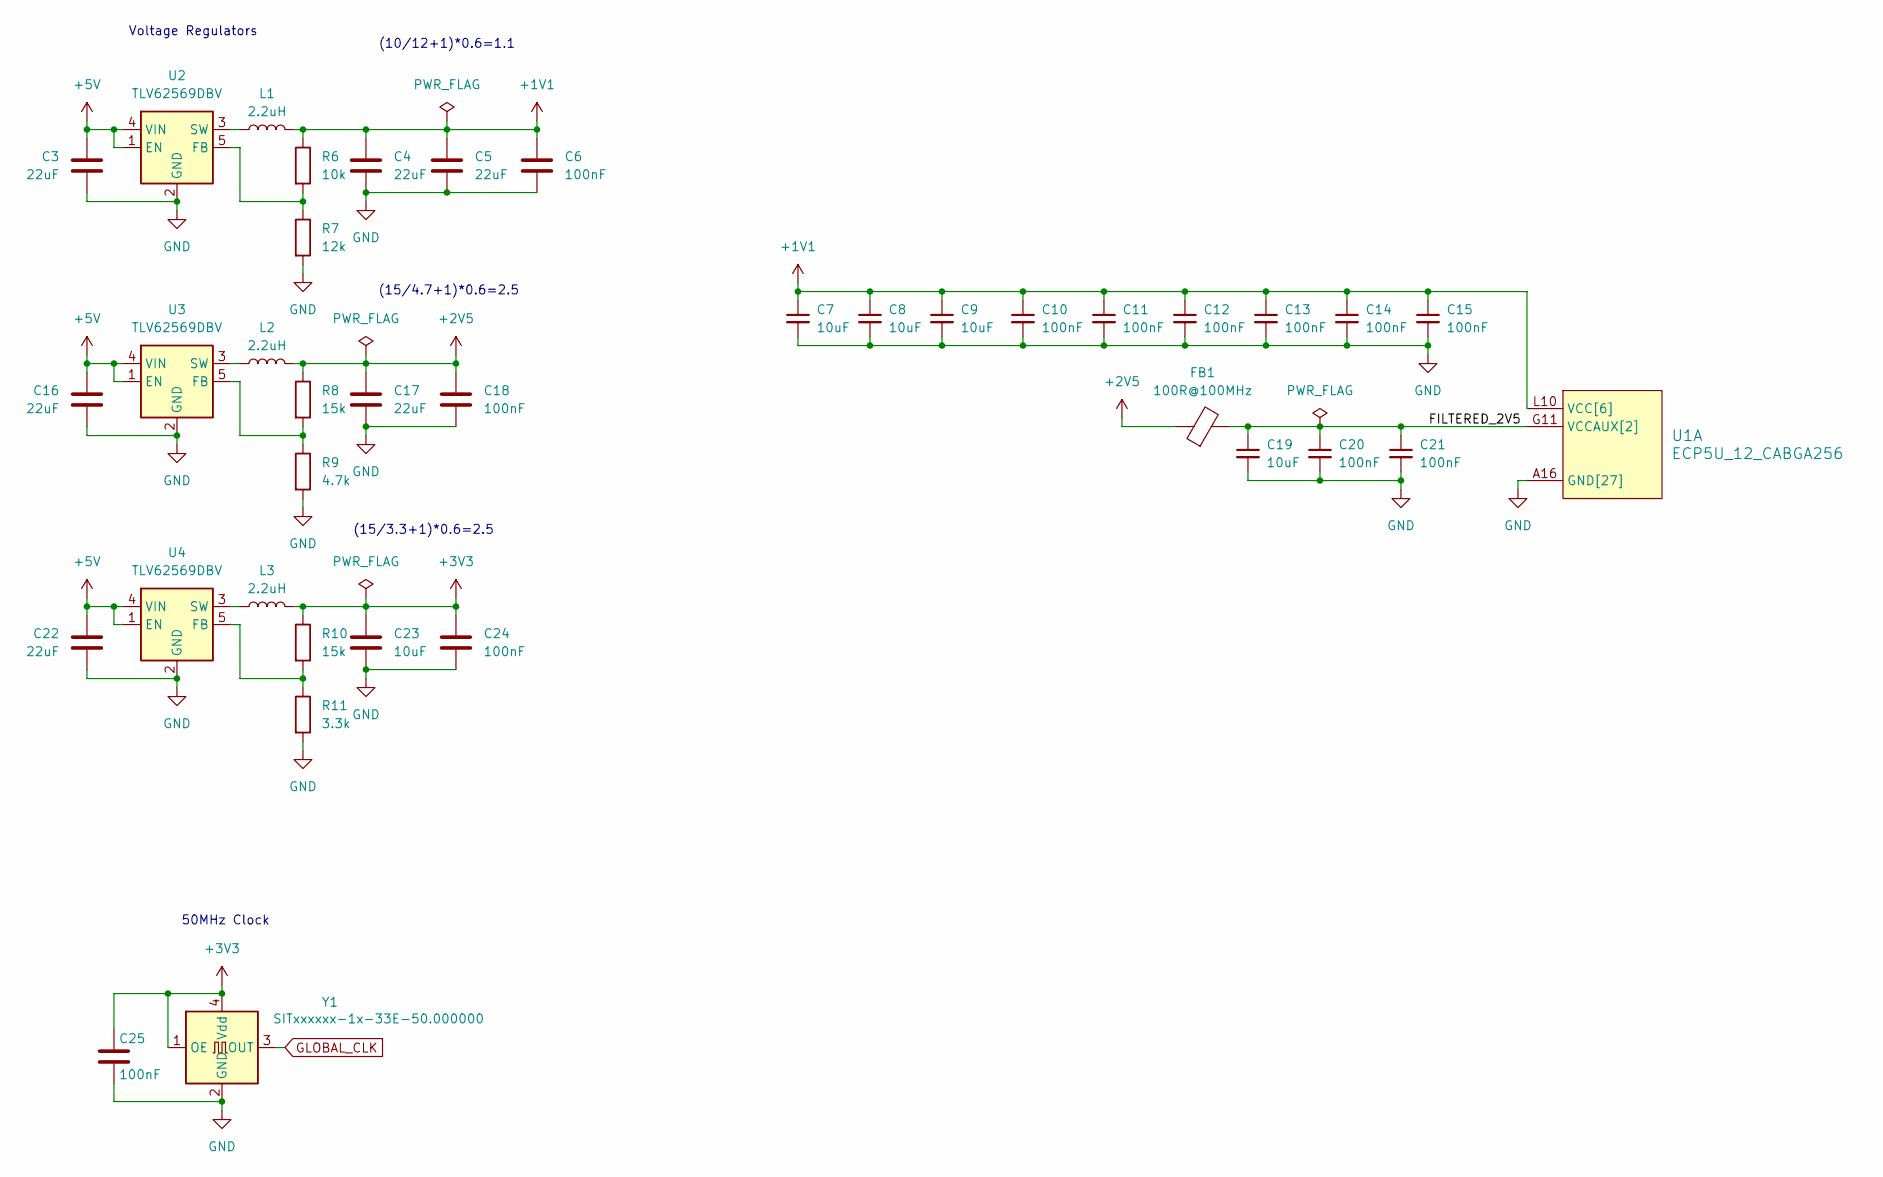
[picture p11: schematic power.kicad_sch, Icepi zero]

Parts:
C3, C4, C5, C16, C17, C22: 22uF; C_0603_1608Metric; LCSC Part # C59461
C6, C10, C11, C12, C13, C14, C15, C18, C20, C21, C24, C25: 100nF; C_0402_1005Metric; LCSC Part # C307331
C7, C8, C9, C19, C23: 10uF; C_0603_1608Metric; LCSC Part # C19702
FB1: 100R@100MHz; L_0805_2012Metric; LCSC Part # C1015
L1, L2, L3: 2.2uH; L_0805_2012Metric; LCSC Part # C1043
R6: 10k; R_0402_1005Metric; LCSC Part # C25744
R7: 12k; R_0402_1005Metric; LCSC Part # C25752
R8, R10: 15k; R_0402_1005Metric; LCSC Part # C25756
R9: 4.7k; R_0402_1005Metric; LCSC Part # C25900
R11: 3.3k; R_0402_1005Metric; LCSC Part # C25890
U1: ECP5U_12_CABGA256; BGA-256_14.0x14.0mm_Layout16x16_P0.8mm_Ball0.45mm_Pad0.32mm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; LCSC Part # C1521614
U2, U3, U4: TLV62569DBV; SOT-23-5; LCSC Part # C141836
Y1: SITxxxxxx-1x-33E-50.000000; Oscillator_SMD_SiT_PQFN-4Pin_2.5x2.0mm; LCSC Part # C1182928

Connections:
+1V1: C4.1, C5.1, C6.1, C7.1, C8.1, C9.1, C10.1, C11.1, C12.1, C13.1, C14.1, C15.1, L1.2, R6.1, U1.G6 (VCC[6]), U1.G7 (VCC[6]), U1.G9 (VCC[6]), U1.L8 (VCC[6]), U1.L9 (VCC[6]), U1.L10 (VCC[6]); also elsewhere on the board
+2V5: C17.1, C18.1, FB1.1, L2.2, R8.1; also elsewhere on the board
+3V3: C23.1, C24.1, C25.1, L3.2, R10.1, Y1.1 (OE), Y1.4 (Vdd); also elsewhere on the board
+5V: C3.1, C16.1, C22.1, U2.1 (EN), U2.4 (VIN), U3.1 (EN), U3.4 (VIN), U4.1 (EN), U4.4 (VIN); also elsewhere on the board
/Power/FILTERED_2V5: C19.1, C20.1, C21.1, FB1.2, U1.G11 (VCCAUX[2]), U1.L7 (VCCAUX[2])
GLOBAL_CLK: Y1.3 (OUT); also elsewhere on the board
GND: C3.2, C4.2, C5.2, C6.2, C7.2, C8.2, C9.2, C10.2, C11.2, C12.2, C13.2, C14.2, C15.2, C16.2, C17.2, C18.2, C19.2, C20.2, C21.2, C22.2, C23.2, C24.2, C25.2, R7.2, R9.2, R11.2, U1.A1 (GND[27]), U1.A16 (GND[27]), U1.D2 (GND[27]), U1.D15 (GND[27]), U1.F8 (GND[27]), U1.F9 (GND[27]), U1.G8 (GND[27]), U1.G10 (GND[27]), U1.H1 (GND[27]), U1.H8 (GND[27]), U1.H9 (GND[27]), U1.H10 (GND[27]), U1.H16 (GND[27]), U1.J8 (GND[27]), U1.J9 (GND[27]), U1.J10 (GND[27]), U1.K6 (GND[27]), U1.K7 (GND[27]), U1.K8 (GND[27]), U1.K9 (GND[27]), U1.K10 (GND[27]), U1.N2 (GND[27]), U1.N15 (GND[27]), U1.T1 (GND[27]), U1.T5 (GND[27]), U1.T12 (GND[27]), U1.T16 (GND[27]), U2.2 (GND), U3.2 (GND), U4.2 (GND), Y1.2 (GND); also elsewhere on the board
unnamed: R6.2, R7.1, U2.5 (FB)
unnamed: L1.1, U2.3 (SW)
unnamed: R8.2, R9.1, U3.5 (FB)
unnamed: L2.1, U3.3 (SW)
unnamed: R10.2, R11.1, U4.5 (FB)
unnamed: L3.1, U4.3 (SW)

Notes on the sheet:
(15/4.7+1)*0.6=2.5
(10/12+1)*0.6=1.1
(15/3.3+1)*0.6=2.5
50MHz Clock
Voltage Regulators

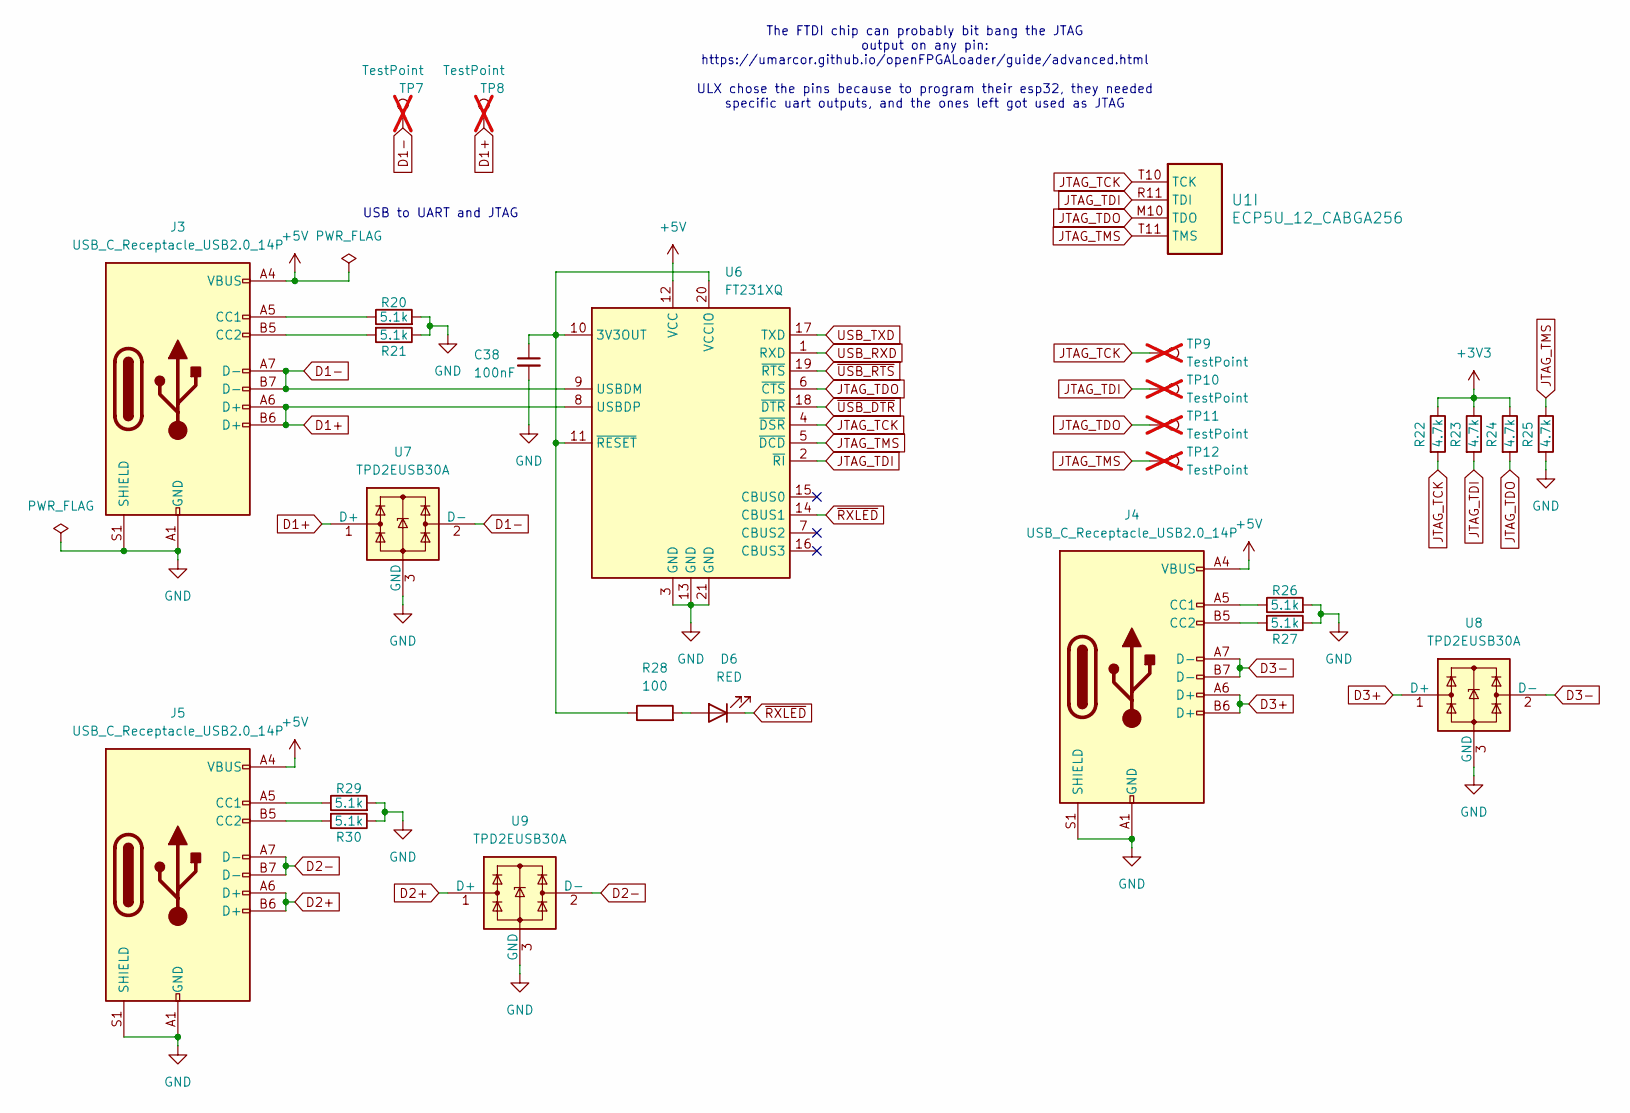
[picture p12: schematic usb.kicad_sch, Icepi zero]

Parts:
C38: 100nF; C_0402_1005Metric; LCSC Part # C307331
D6: RED; LED_0603_1608Metric; LCSC Part # C2286
J3, J4, J5: USB_C_Receptacle_USB2.0_14P; USB_C_Receptacle_GCT_USB4105-xx-A_16P_TopMnt_Horizontal; LCSC Part # C2765186
R20, R21, R26, R27, R29, R30: 5.1k; R_0402_1005Metric; LCSC Part # C25905
R22, R23, R24, R25: 4.7k; R_0402_1005Metric; LCSC Part # C25900
R28: 100; R_0402_1005Metric; LCSC Part # C25076
TP7, TP8: TestPoint; TestPoint_Pad_D2.0mm; not fitted
TP9, TP10, TP11, TP12: TestPoint; TestPoint_Pad_D1.0mm; not fitted
U1: ECP5U_12_CABGA256; BGA-256_14.0x14.0mm_Layout16x16_P0.8mm_Ball0.45mm_Pad0.32mm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; LCSC Part # C1521614
U6: FT231XQ; QFN-20-1EP_4x4mm_P0.5mm_EP2.5x2.5mm; LCSC Part # C132159
U7, U8, U9: TPD2EUSB30A; Texas_DRT-3; LCSC Part # C3011197

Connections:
+3V3: R22.1, R23.1, R24.1; also elsewhere on the board
+5V: J3.A4 (VBUS), J3.A9 (VBUS), J3.B4 (VBUS), J3.B9 (VBUS), J4.A4 (VBUS), J4.A9 (VBUS), J4.B4 (VBUS), J4.B9 (VBUS), J5.A4 (VBUS), J5.A9 (VBUS), J5.B4 (VBUS), J5.B9 (VBUS), U6.12 (VCC); also elsewhere on the board
D1+: J3.A6 (D+), J3.B6 (D+), TP8.1, U6.8 (USBDP), U7.1 (D+)
D1-: J3.A7 (D-), J3.B7 (D-), TP7.1, U6.9 (USBDM), U7.2 (D-)
D2+: J5.A6 (D+), J5.B6 (D+), U9.1 (D+); also elsewhere on the board
D2-: J5.A7 (D-), J5.B7 (D-), U9.2 (D-); also elsewhere on the board
D3+: J4.A6 (D+), J4.B6 (D+), U8.1 (D+); also elsewhere on the board
D3-: J4.A7 (D-), J4.B7 (D-), U8.2 (D-); also elsewhere on the board
GND: C38.2, J3.A1 (GND), J3.A12 (GND), J3.B1 (GND), J3.B12 (GND), J3.S1 (SHIELD), J4.A1 (GND), J4.A12 (GND), J4.B1 (GND), J4.B12 (GND), J4.S1 (SHIELD), J5.A1 (GND), J5.A12 (GND), J5.B1 (GND), J5.B12 (GND), J5.S1 (SHIELD), R20.2, R21.1, R25.2, R26.2, R27.1, R29.2, R30.1, U6.3 (GND), U6.13 (GND), U6.21 (GND), U7.3 (GND), U8.3 (GND), U9.3 (GND); also elsewhere on the board
JTAG_TCK: R22.2, TP9.1, U1.T10 (TCK), U6.4 (~DSR)
JTAG_TDI: R23.2, TP10.1, U1.R11 (TDI), U6.2 (~RI)
JTAG_TDO: R24.2, TP11.1, U1.M10 (TDO), U6.6 (~CTS)
JTAG_TMS: R25.1, TP12.1, U1.T11 (TMS), U6.5 (~DCD)
unnamed: D6.2 (A), R28.2
unnamed: J3.A5 (CC1), R20.1
unnamed: J3.B5 (CC2), R21.2
unnamed: J4.A5 (CC1), R26.1
unnamed: J4.B5 (CC2), R27.2
unnamed: J5.A5 (CC1), R29.1
unnamed: J5.B5 (CC2), R30.2
unnamed: C38.1, R28.1, U6.10 (3V3OUT), U6.11 (~RESET), U6.20 (VCCIO)
USB_RXD: U6.1 (RXD); also elsewhere on the board
USB_TXD: U6.17 (TXD); also elsewhere on the board
~RXLED: D6.1 (K), U6.14 (CBUS1)
~USB_DTR: U6.18 (~DTR); also elsewhere on the board
~USB_RTS: U6.19 (~RTS); also elsewhere on the board

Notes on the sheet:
USB to UART and JTAG
The FTDI chip can probably bit bang the JTAG output on any pin: https://umarcor.github.io/openFPGALoader/guide/advanced.html ULX chose the pins because to program their esp32, they needed specific uart outputs, and the ones left got used as JTAG

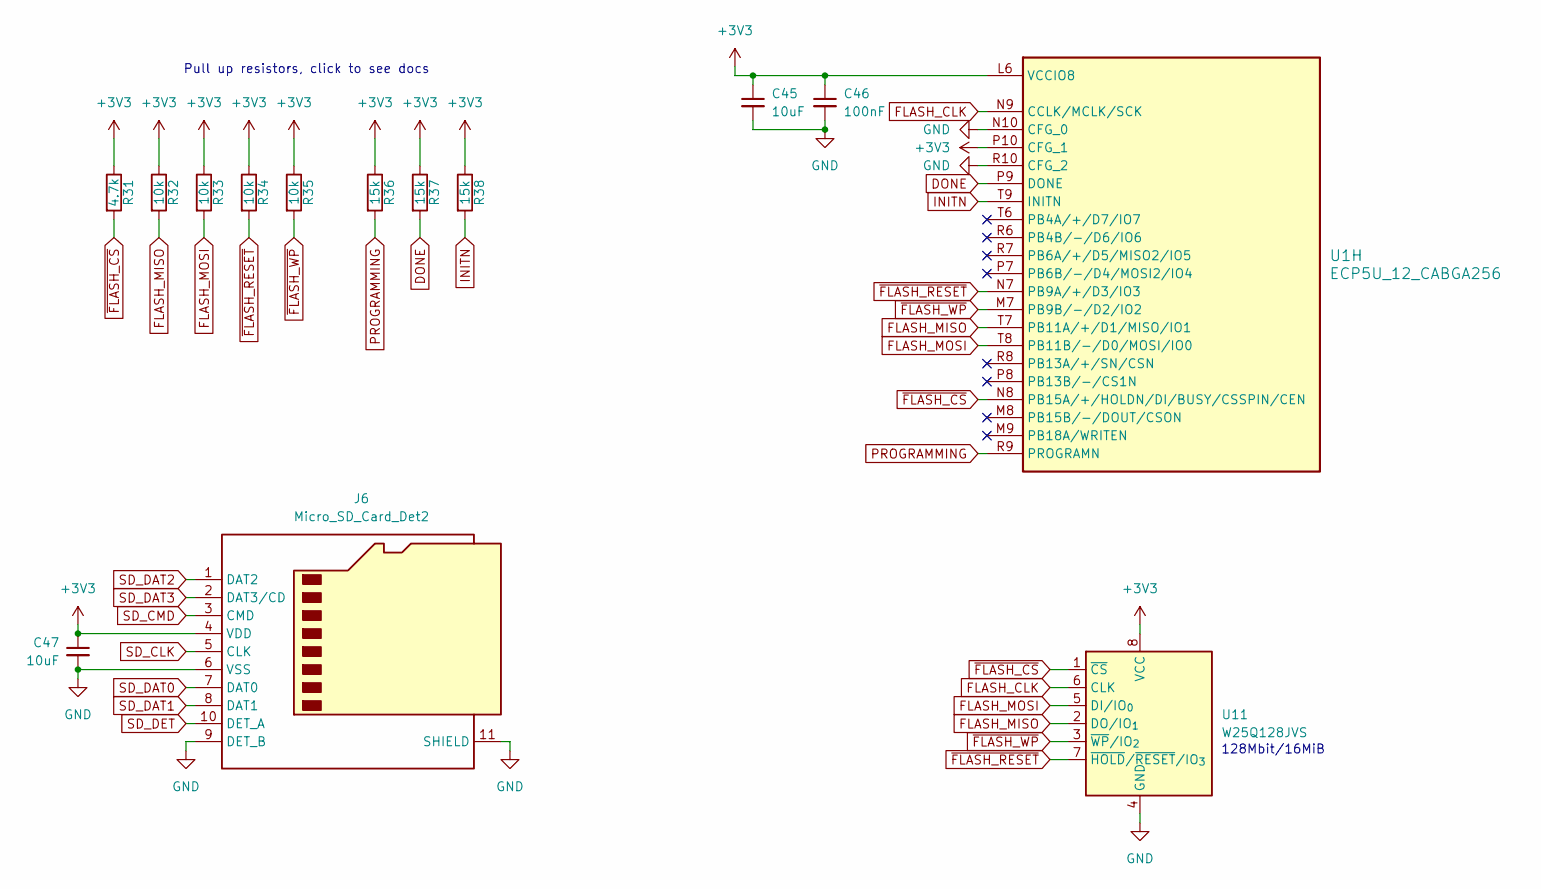
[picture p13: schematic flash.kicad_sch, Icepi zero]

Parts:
C45, C47: 10uF; C_0603_1608Metric; LCSC Part # C19702
C46: 100nF; C_0402_1005Metric; LCSC Part # C307331
J6: Micro_SD_Card_Det2; microSD_HC_SOFNG_TF-008; LCSC Part # C428465
R31: 4.7k; R_0402_1005Metric; LCSC Part # C25900
R32, R33, R34, R35: 10k; R_0402_1005Metric; LCSC Part # C25744
R36, R37, R38: 15k; R_0402_1005Metric; LCSC Part # C25756
U1: ECP5U_12_CABGA256; BGA-256_14.0x14.0mm_Layout16x16_P0.8mm_Ball0.45mm_Pad0.32mm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; LCSC Part # C1521614
U11: W25Q128JVS; SOIC-8_5.3x5.3mm_P1.27mm; LCSC Part # C97521

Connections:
+3V3: C45.1, C46.1, C47.1, J6.4 (VDD), R31.1, R32.1, R33.1, R34.1, R35.1, R36.1, R37.1, R38.1, U1.L6 (VCCIO8), U1.P10 (CFG_1), U11.8 (VCC); also elsewhere on the board
DONE: R37.2, U1.P9 (DONE)
FLASH_CLK: U1.N9 (CCLK/MCLK/SCK), U11.6 (CLK)
FLASH_MISO: R32.2, U1.T7 (PB11A/+/D1/MISO/IO1), U11.2 (DO/IO_{1})
FLASH_MOSI: R33.2, U1.T8 (PB11B/-/D0/MOSI/IO0), U11.5 (DI/IO_{0})
GND: C45.2, C46.2, C47.2, J6.6 (VSS), J6.9 (DET_B), J6.11 (SHIELD), U1.N10 (CFG_0), U1.R10 (CFG_2), U11.4 (GND); also elsewhere on the board
INITN: R38.2, U1.T9 (INITN)
PROGRAMMING: R36.2, U1.R9 (PROGRAMN)
SD_CLK: J6.5 (CLK); also elsewhere on the board
SD_CMD: J6.3 (CMD); also elsewhere on the board
SD_DAT0: J6.7 (DAT0); also elsewhere on the board
SD_DAT1: J6.8 (DAT1); also elsewhere on the board
SD_DAT2: J6.1 (DAT2); also elsewhere on the board
SD_DAT3: J6.2 (DAT3/CD); also elsewhere on the board
SD_DET: J6.10 (DET_A); also elsewhere on the board
~FLASH_CS: R31.2, U1.N8 (PB15A/+/HOLDN/DI/BUSY/CSSPIN/CEN), U11.1 (~CS)
~FLASH_RESET: R34.2, U1.N7 (PB9A/+/D3/IO3), U11.7 (~HOLD/~RESET/IO_{3})
~FLASH_WP: R35.2, U1.M7 (PB9B/-/D2/IO2), U11.3 (~WP/IO_{2})

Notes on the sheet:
128Mbit/16MiB
Pull up resistors, click to see docs

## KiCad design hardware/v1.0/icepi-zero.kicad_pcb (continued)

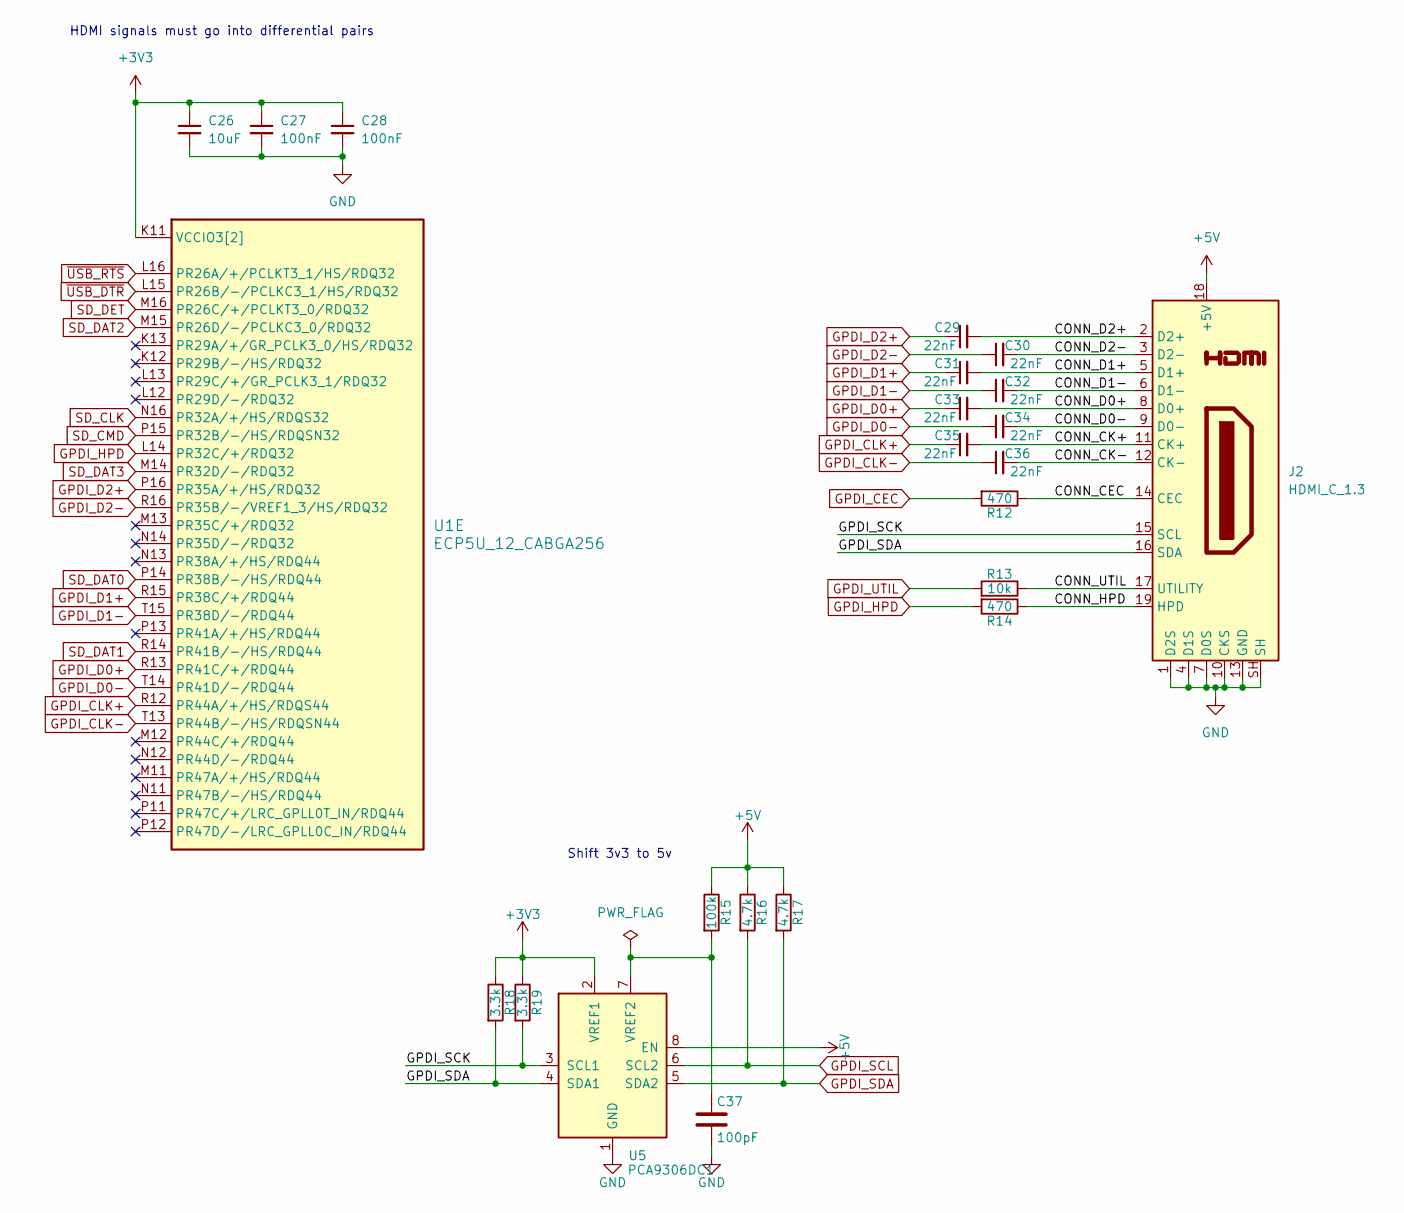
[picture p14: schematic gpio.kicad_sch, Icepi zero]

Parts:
C26: 10uF; C_0603_1608Metric; LCSC Part # C19702
C27, C28: 100nF; C_0402_1005Metric; LCSC Part # C307331
C29, C30, C31, C32, C33, C34, C35, C36: 22nF; C_0402_1005Metric; LCSC Part # C1532
C37: 100pF; C_0402_1005Metric; LCSC Part # C1546
J2: HDMI_C_1.3; XKB Connection A71-05H4-111N1; LCSC Part # C2682170
R12, R14: 470; R_0402_1005Metric; LCSC Part # C25117
R13: 10k; R_0402_1005Metric; LCSC Part # C25744
R15: 100k; R_0402_1005Metric; LCSC Part # C25741
R16, R17: 4.7k; R_0402_1005Metric; LCSC Part # C25900
R18, R19: 3.3k; R_0402_1005Metric; LCSC Part # C25890
U1: ECP5U_12_CABGA256; BGA-256_14.0x14.0mm_Layout16x16_P0.8mm_Ball0.45mm_Pad0.32mm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; LCSC Part # C1521614
U5: PCA9306DC1; VSSOP-8_2.3x2mm_P0.5mm; LCSC Part # C129510

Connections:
+3V3: C26.1, C27.1, C28.1, R18.1, R19.1, U1.K11 (VCCIO3[2]), U1.L11 (VCCIO3[2]), U5.2 (VREF1); also elsewhere on the board
+5V: J2.18 (+5V), R15.1, R16.1, R17.1, U5.8 (EN); also elsewhere on the board
/GPIO/CONN_CEC: J2.14 (CEC), R12.1
/GPIO/CONN_CK+: C35.2, J2.11 (CK+)
/GPIO/CONN_CK-: C36.2, J2.12 (CK-)
/GPIO/CONN_D0+: C33.2, J2.8 (D0+)
/GPIO/CONN_D0-: C34.2, J2.9 (D0-)
/GPIO/CONN_D1+: C31.2, J2.5 (D1+)
/GPIO/CONN_D1-: C32.2, J2.6 (D1-)
/GPIO/CONN_D2+: C29.2, J2.2 (D2+)
/GPIO/CONN_D2-: C30.2, J2.3 (D2-)
/GPIO/CONN_HPD: J2.19 (HPD), R14.1
/GPIO/CONN_UTIL: J2.17 (UTILITY), R13.1
/GPIO/GPDI_SCK: J2.15 (SCL), R19.2, U5.3 (SCL1)
GND: C26.2, C27.2, C28.2, C37.2, J2.1 (D2S), J2.4 (D1S), J2.7 (D0S), J2.10 (CKS), J2.13 (GND), J2.SH, U5.1 (GND); also elsewhere on the board
GPDI_CEC: R12.2; also elsewhere on the board
GPDI_CLK+: C35.1, U1.R12 (PR44A/+/HS/RDQS44)
GPDI_CLK-: C36.1, U1.T13 (PR44B/-/HS/RDQSN44)
GPDI_D0+: C33.1, U1.R13 (PR41C/+/RDQ44)
GPDI_D0-: C34.1, U1.T14 (PR41D/-/RDQ44)
GPDI_D1+: C31.1, U1.R15 (PR38C/+/RDQ44)
GPDI_D1-: C32.1, U1.T15 (PR38D/-/RDQ44)
GPDI_D2+: C29.1, U1.P16 (PR35A/+/HS/RDQ32)
GPDI_D2-: C30.1, U1.R16 (PR35B/-/VREF1_3/HS/RDQ32)
GPDI_HPD: R14.2, U1.L14 (PR32C/+/RDQ32)
GPDI_SCL: R16.2, U5.6 (SCL2); also elsewhere on the board
GPDI_SDA: J2.16 (SDA), R17.2, R18.2, U5.4 (SDA1), U5.5 (SDA2); also elsewhere on the board
GPDI_UTIL: R13.2; also elsewhere on the board
unnamed: C37.1, R15.2, U5.7 (VREF2)
SD_CLK: U1.N16 (PR32A/+/HS/RDQS32); also elsewhere on the board
SD_CMD: U1.P15 (PR32B/-/HS/RDQSN32); also elsewhere on the board
SD_DAT0: U1.P14 (PR38B/-/HS/RDQ44); also elsewhere on the board
SD_DAT1: U1.R14 (PR41B/-/HS/RDQ44); also elsewhere on the board
SD_DAT2: U1.M15 (PR26D/-/PCLKC3_0/RDQ32); also elsewhere on the board
SD_DAT3: U1.M14 (PR32D/-/RDQ32); also elsewhere on the board
SD_DET: U1.M16 (PR26C/+/PCLKT3_0/RDQ32); also elsewhere on the board
~USB_DTR: U1.L15 (PR26B/-/PCLKC3_1/HS/RDQ32); also elsewhere on the board
~USB_RTS: U1.L16 (PR26A/+/PCLKT3_1/HS/RDQ32); also elsewhere on the board

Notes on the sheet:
Shift 3v3 to 5v
HDMI signals must go into differential pairs

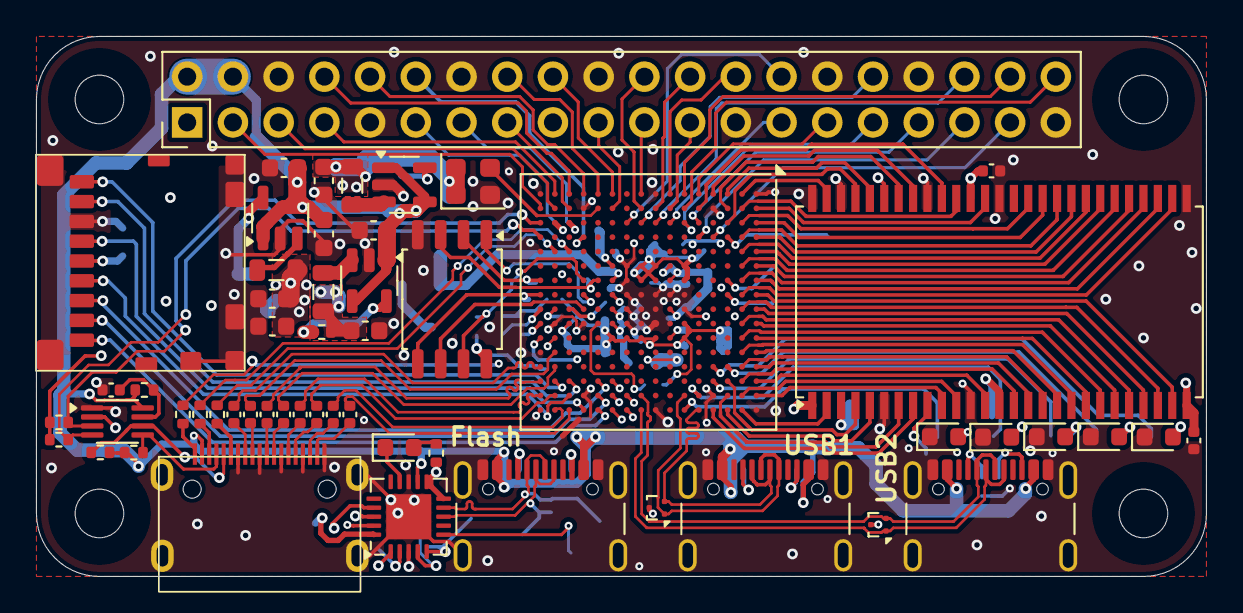
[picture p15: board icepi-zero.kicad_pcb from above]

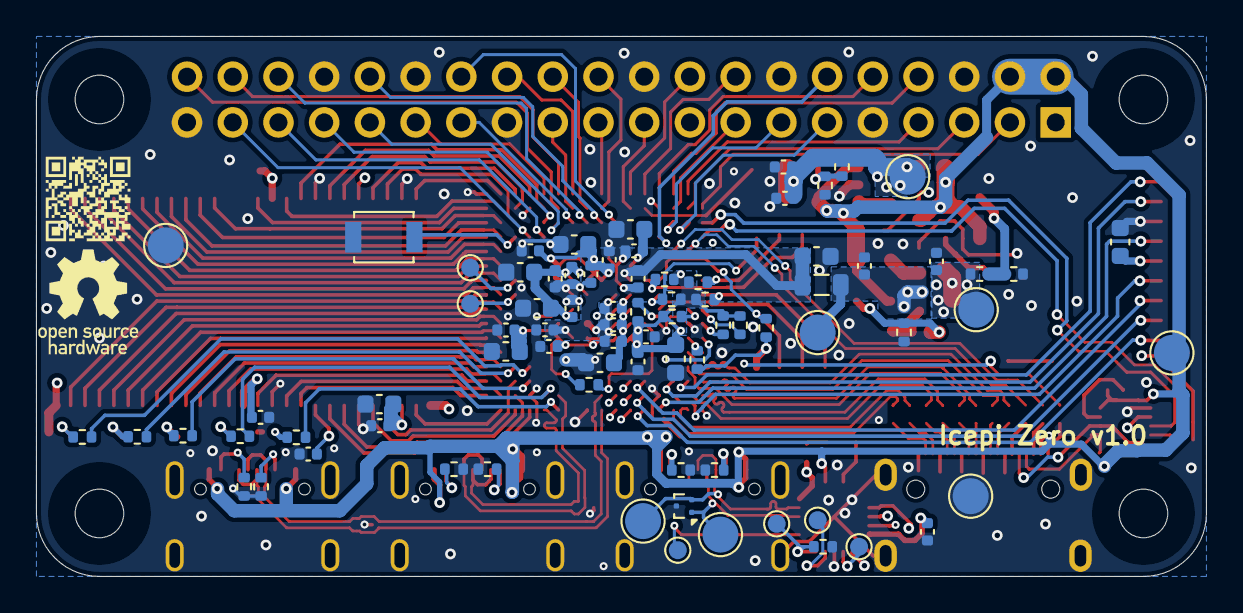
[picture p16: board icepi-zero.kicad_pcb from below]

Board: 4 copper layers, 65.0 x 30.0 mm, 137 parts (79 on the bottom side), 158 nets.

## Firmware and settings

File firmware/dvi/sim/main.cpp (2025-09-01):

#include <iostream>
#include <string>

#include <boost/program_options.hpp>
namespace po = boost::program_options;

#include <SDL3/SDL.h>

#include <verilated.h>
#include <verilated_vcd_c.h>

#include "../obj_dir/Vvga.h"

constexpr int DEFAULT_W = 640;
constexpr int DEFAULT_H = 480;

static auto destroyWindow = [](SDL_Window* w) { SDL_DestroyWindow(w); };
static auto destroyRenderer = [](SDL_Renderer* r) { SDL_DestroyRenderer(r); };
static auto destroyTexture = [](SDL_Texture* r) { SDL_DestroyTexture(r); };

static std::unique_ptr<SDL_Window, decltype(destroyWindow)> window;
static std::unique_ptr<SDL_Renderer, decltype(destroyRenderer)> renderer;
static std::unique_ptr<SDL_Texture, decltype(destroyTexture)> texture;
static std::unique_ptr<std::uint32_t> screen;

static int frames;
static std::uint64_t ticks;

int setupVGA() {
    SDL_SetAppMetadata("VGA simulator", "1.0", "com.cyao.vgasimulator");
    if (!SDL_Init(SDL_INIT_VIDEO)) {
        SDL_Log("Couldn't initialize SDL: %s", SDL_GetError());
        return 1;
    }

    if (!SDL_CreateWindowAndRenderer("VGA verilog simulator", DEFAULT_W, DEFAULT_H, 0,
                                     std::out_ptr(window), std::out_ptr(renderer))) {
        SDL_Log("Couldn't create window/renderer: %s", SDL_GetError());
        return 1;
    }

    texture = decltype(texture)(SDL_CreateTexture(renderer.get(), SDL_PIXELFORMAT_RGBA8888,
                                        SDL_TEXTUREACCESS_STREAMING, DEFAULT_W, DEFAULT_H));

	SDL_SetRenderDrawBlendMode(renderer.get(), SDL_BLENDMODE_NONE);
	SDL_SetTextureBlendMode(texture.get(), SDL_BLENDMODE_NONE);
	SDL_SetWindowPosition(window.get(), SDL_WINDOWPOS_CENTERED, SDL_WINDOWPOS_CENTERED);
	SDL_RaiseWindow(window.get());

    screen = decltype(screen)(new std::uint32_t[DEFAULT_W * DEFAULT_H]);

    SDL_memset(screen.get(), 0xFF, DEFAULT_W * DEFAULT_H * 4);

    return 0;
}

int drawVGA(Vvga* vga) {
    static int x;

    static int pitch;
	static void* pixels;

    if (vga->de) {
        screen.get()[x] = (static_cast<std::uint32_t>(vga->vga_b) <<  8) ^
                          (static_cast<std::uint32_t>(vga->vga_g) << 16) ^
                          (static_cast<std::uint32_t>(vga->vga_r) << 24);

        x += 1;
    } else {
        // Let us quit
        SDL_Event e;
        SDL_PollEvent(&e);
        [[unlikely]] if (e.type == SDL_EVENT_QUIT) {
            return 1;
        }

        if (!vga->vsync && x != 0) {
            x = 0;

            SDL_LockTexture(texture.get(), NULL, &pixels, &pitch);

            assert(pitch == sizeof(std::uint32_t) * DEFAULT_W);

            SDL_memcpy(pixels, screen.get(), DEFAULT_W * DEFAULT_H * sizeof(std::uint32_t));
            SDL_UnlockTexture(texture.get());
            SDL_RenderTexture(renderer.get(), texture.get(), NULL, NULL);
            SDL_RenderPresent(renderer.get());

            frames += 1;

            if (SDL_GetTicks() - ticks > 2000) { // Per 2 seconds
                std::cout << "FPS:" << static_cast<float>(frames) / (static_cast<float>(SDL_GetTicks() - ticks) / 1000) << std::endl;
                frames = 0;
                ticks = SDL_GetTicks();
            }
        }

        return 0;
    }

    return 0;
}

int main(int argc, char** argv) {
    // Parse cli options
    po::options_description desc("Allowed options");
    desc.add_options()
        ("help",      "display this text and exit")
        ("trace",     "produce waveform dump")
        ("tracefile", po::value<std::string>()->default_value("wave.vcd"), "waveform file name")
    ;

    po::variables_map vm;
    po::store(po::parse_command_line(argc, argv, desc), vm);
    po::notify(vm);

    // Print help message
    if (vm.count("help")) {
        std::cout << desc << "\n";
        return 1;
    }

    if (setupVGA()) {
        return 1;
    }

    Verilated::mkdir("logs");
    VerilatedVcdC* tfp = nullptr;
    VerilatedContext* const contextp = new VerilatedContext;
    contextp->debug(0); // 0 is off, 9 highest
    
    bool trace = false;
    if (vm.count("trace")) {
        contextp->traceEverOn(true);
        trace = true;
    } else {
        contextp->traceEverOn(false);
    }

    contextp->commandArgs(argc, argv);

    const auto top = std::unique_ptr<Vvga>(new Vvga(contextp, "TOP"));
    // Trace to 99 depth
    if (trace) {
        tfp = new VerilatedVcdC;
        top->trace(tfp, 99);
        tfp->open(vm["tracefile"].as<std::string>().data());
    }

    ticks = SDL_GetTicks();
    while (!contextp->gotFinish()) {
        contextp->timeInc(1); // Time is passing uwu
        top->clkp = !top->clkp; // 50MHz clock
        
        // Signals are posedge in verilog, so we change on negedge
        if (!top->clkp) {
            // TODO: LED and btn

            if (drawVGA(top.get())) {
                // Quit
                return 0;
            }
        }

        top->eval();

        if (trace) {
            tfp->dump(contextp->time());
        }
    }

    if (trace) {
        tfp->close();
    }
    top->final();
}

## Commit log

2025-04-29 Start of everything
    [bom.csv, designators.csv, flash.kicad_sch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]
2025-05-01 Routed most of sdram
    [flash.kicad_sch, gpio.kicad_sch, icepi-zero.kicad_pcb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]
2025-05-03 Routed power
    [flash.kicad_sch, gpio.kicad_sch, icepi-zero.kicad_pcb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]
2025-05-03 Added the decoupling capacitors
    [bom.csv, designators.csv, flash.kicad_sch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]
2025-05-04 V1.0 Final Revision and Readme documentation
    [bom.csv, designators.csv, ecp5.kicad_sch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]
2025-05-04 Fix level shifter EN voltage error
    [bom.csv, designators.csv, ecp5.kicad_sch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]
2025-05-06 Add a revision
    [bom.csv, designators.csv, gpio.kicad_sch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]
2025-05-08 Pre-prod fixes
    [bom.csv, designators.csv, ecp5.kicad_sch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]
2025-05-08 Add a button
    [ecp5.kicad_sch, icepi-zero.kicad_pcb, icepi-zero.kicad_sch]
2025-05-10 Final revision
    [bom.csv, ecp5.kicad_sch, flash.kicad_sch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]
2025-05-12 Last checks
    [bom.csv, designators.csv, ecp5.kicad_sch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]
2025-05-13 Final production files
    [bom.csv, icepi-zero.kicad_pcb, icepi-zero.kicad_sch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]
2025-05-19 Stash v1.0, start of firmware
    [bom.csv, designators.csv, ecp5.kicad_sch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]
2025-05-21 Forgot to commit yesterday
    [gpio.kicad_sch, icepi-zero.kicad_pcb, icepi-zero.kicad_sch]
2025-05-21 Finish lpf
    [ecp5.kicad_sch, gpio.kicad_sch, icepi-zero.kicad_pcb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]
2025-05-22 Add blinky example
    [icepi-zero.kicad_pcb]
2025-05-23 Counter example start - button on off
    [icepi-zero.kicad_pcb]
2025-05-25 Add better gitignore
    [icepi-zero.kicad_pcb]
2025-05-26 UART demo
    [icepi-zero.kicad_sch]
2025-05-28 Add memtest
    [icepi-zero.kicad_pcb]
